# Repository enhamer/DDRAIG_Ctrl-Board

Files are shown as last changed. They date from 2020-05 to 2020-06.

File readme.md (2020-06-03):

<!---
#**============================================================================
#**
#**                    Ddraig Control Board
#**                  THIS REPOSITORY IS PART OF THE ENHAMER
#**
#** TITLE:           Ddraig Ctrl PCB (Circuit, Hardware)
#**
#** AUTHOR:          Marcin J. Kraśny
#**
#**					 Advanced Biological Imaging Laboratory
#**                  School of Physics
#**                  College of Science and Engineering
#**                  National University of Ireland, Galway
#**
#** SOURCE URL       https://github.com/enhamer/enhamer
#** COPYRIGHT        © 2015-2020 M.J.Kraśny
#** LICENSE          CERN-OHL-P v2
#** CREDITS          NEMESIS - Novel Energy Materials, Engineering Science 
#**                  and Integrated Systems
#**                  Department of Mechanical Engineering
#**					 University of Bath, UK
#**
#**============================================================================
#**============================================================================
-->
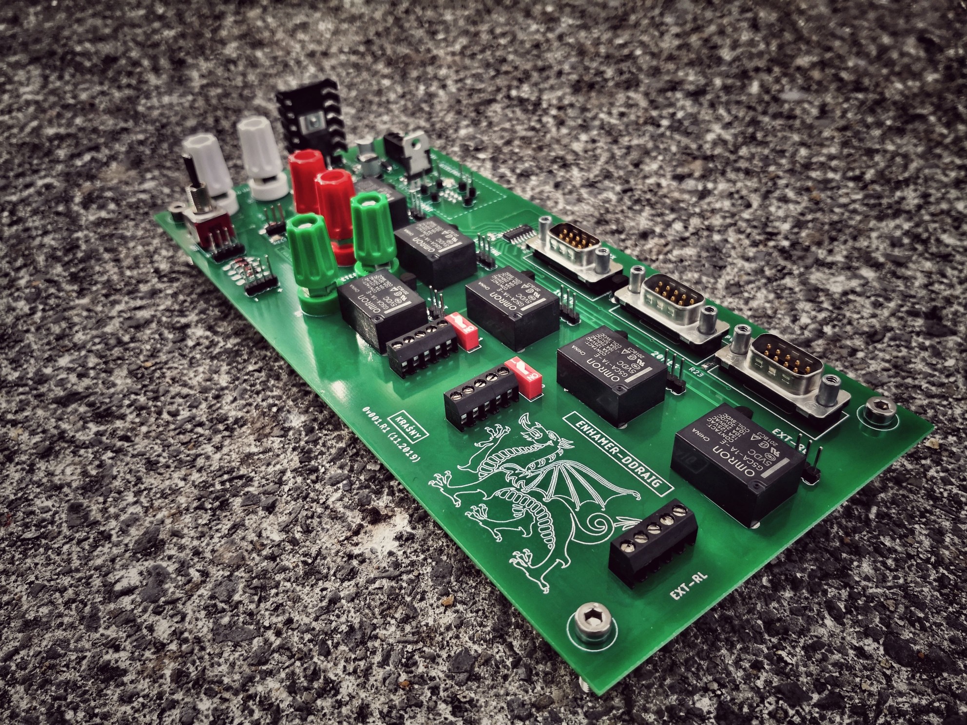
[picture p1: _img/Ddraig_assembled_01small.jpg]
Ddraig Board assembled


# DDRAIG - Control - Board
Part of:
**Energy Harvesting Measurement Rig (ENHAMER)**

*A System for Characterisation of Piezoelectric Materials and Associated Electronics for Vibration Powered Energy Harvesting Devices*

>For detailed **Information, Manuals and Description** please go to [**ENHAMER**](https://github.com/enhamer/enhamer/).

# Design software used
[EAGLE CAD](https://www.autodesk.com/products/eagle/overview)

## Ddraig Board Layout Top Side View
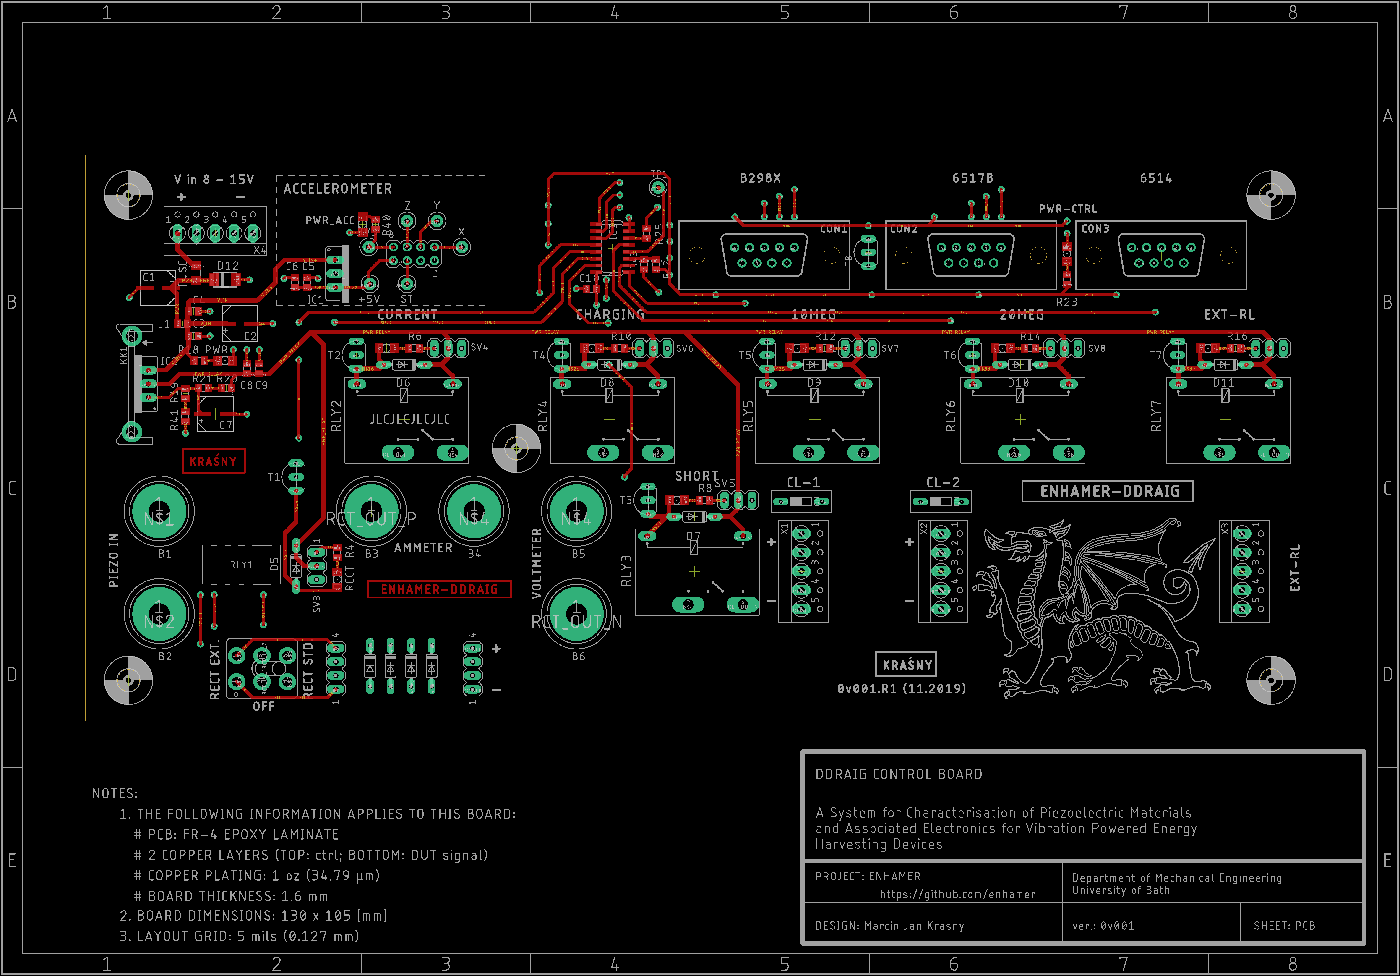
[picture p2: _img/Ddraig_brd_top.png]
Ddraig Board top


## Ddraig Board PCB
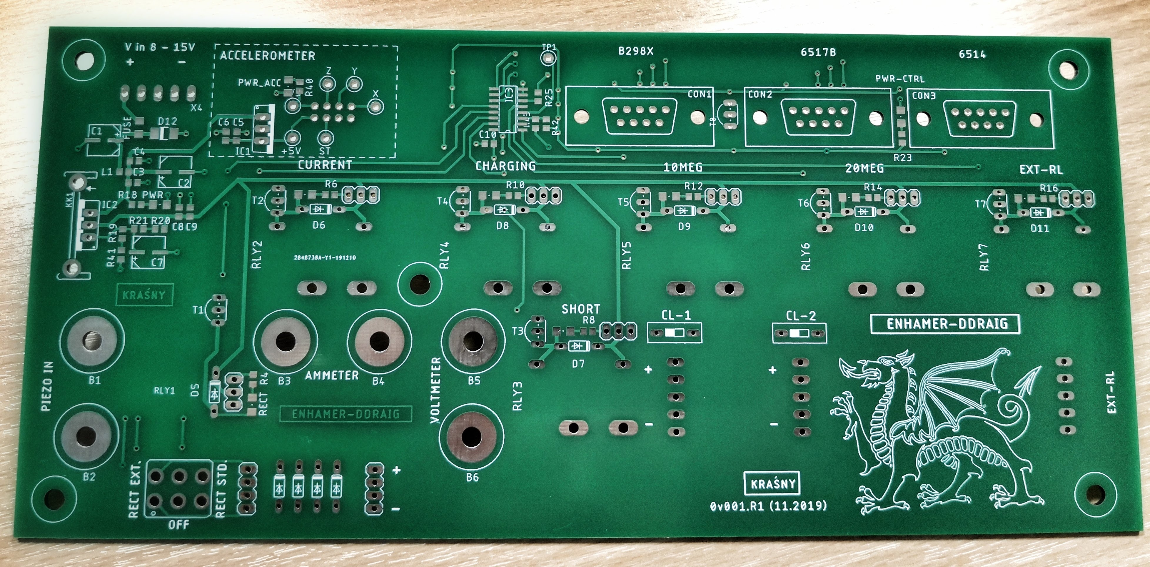
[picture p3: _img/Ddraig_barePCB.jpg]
Ddraig Board top


## Ddraig Board Assembled
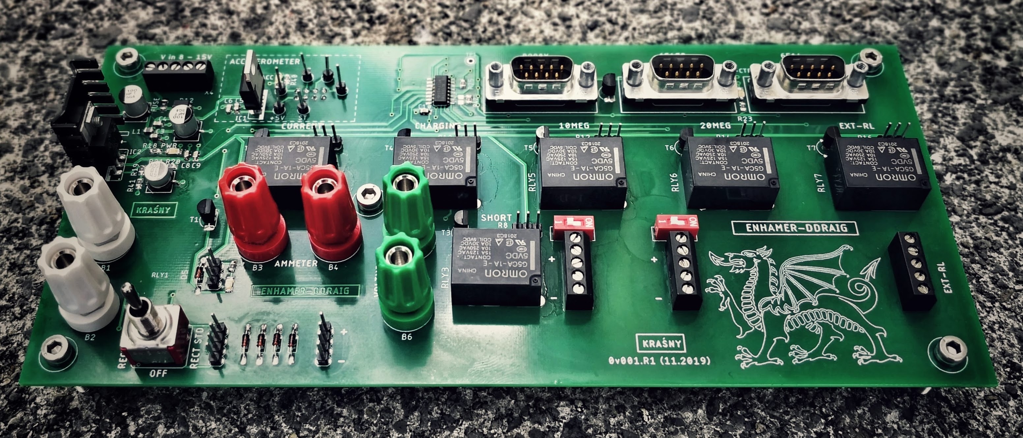
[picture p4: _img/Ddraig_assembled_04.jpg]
Ddraig Board assembled


# License
Copyright © 2015-2020 Marcin J. Kraśny

This work is licensed under the [CERN-OHL-P v2](LICENSE/cern_ohl_p_v2.txt); 
[CERN Open Hardware Licence version 2](https://cern.ch/cern-ohl).

You may redistribute and modify this documentation and make products
using it under the terms of the CERN-OHL-P v2 (<https:/cern.ch/cern-ohl>).
This documentation is distributed WITHOUT ANY EXPRESS OR IMPLIED WARRANTY INCLUDING OF MERCHANTABILITY, SATISFACTORY QUALITY AND FITNESS FOR A PARTICULAR PURPOSE. 
Please see the CERN-OHL-P v2 for applicable conditions.

# SOURCE
[https://github.com/enhamer](https://github.com/enhamer/enhamer/)

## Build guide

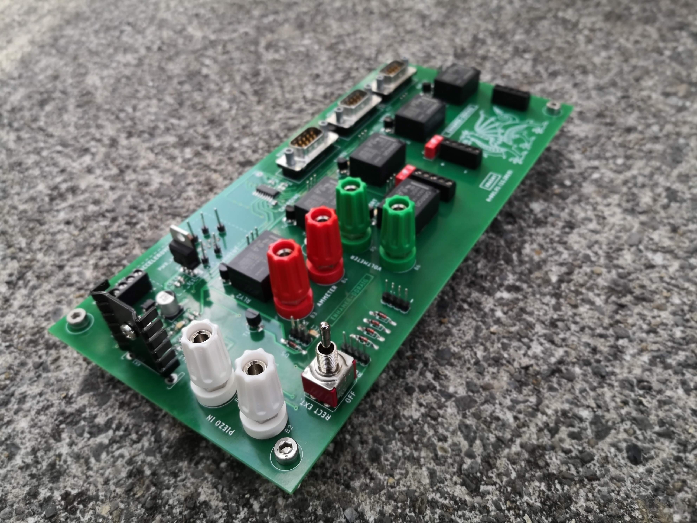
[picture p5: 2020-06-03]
_img/Ddraig_assembled_02.jpg

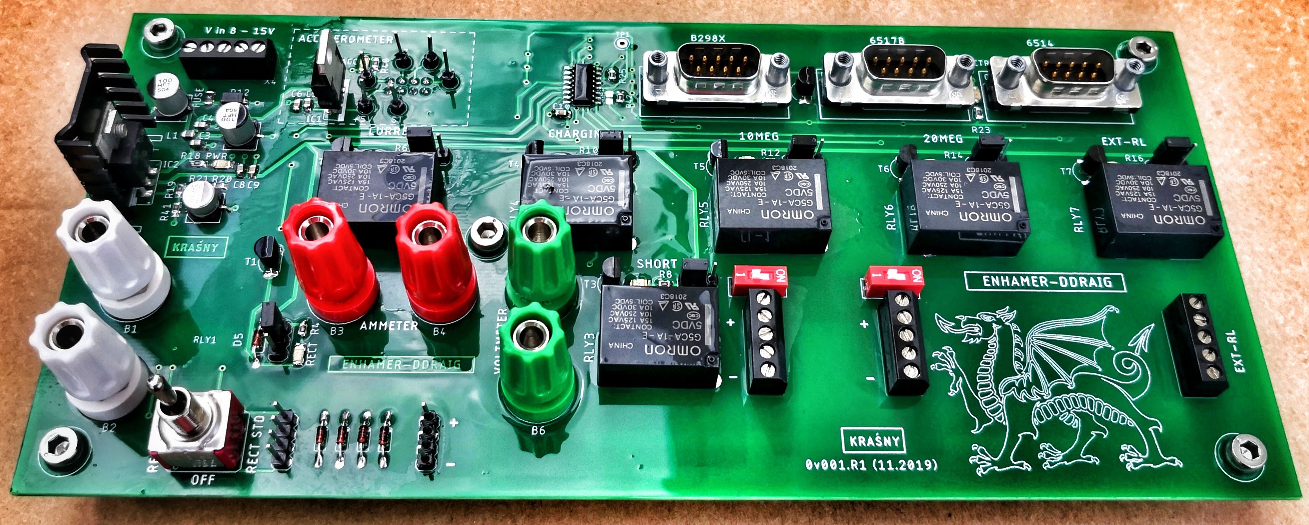
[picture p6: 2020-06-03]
_img/Ddraig_assembled_03.jpg

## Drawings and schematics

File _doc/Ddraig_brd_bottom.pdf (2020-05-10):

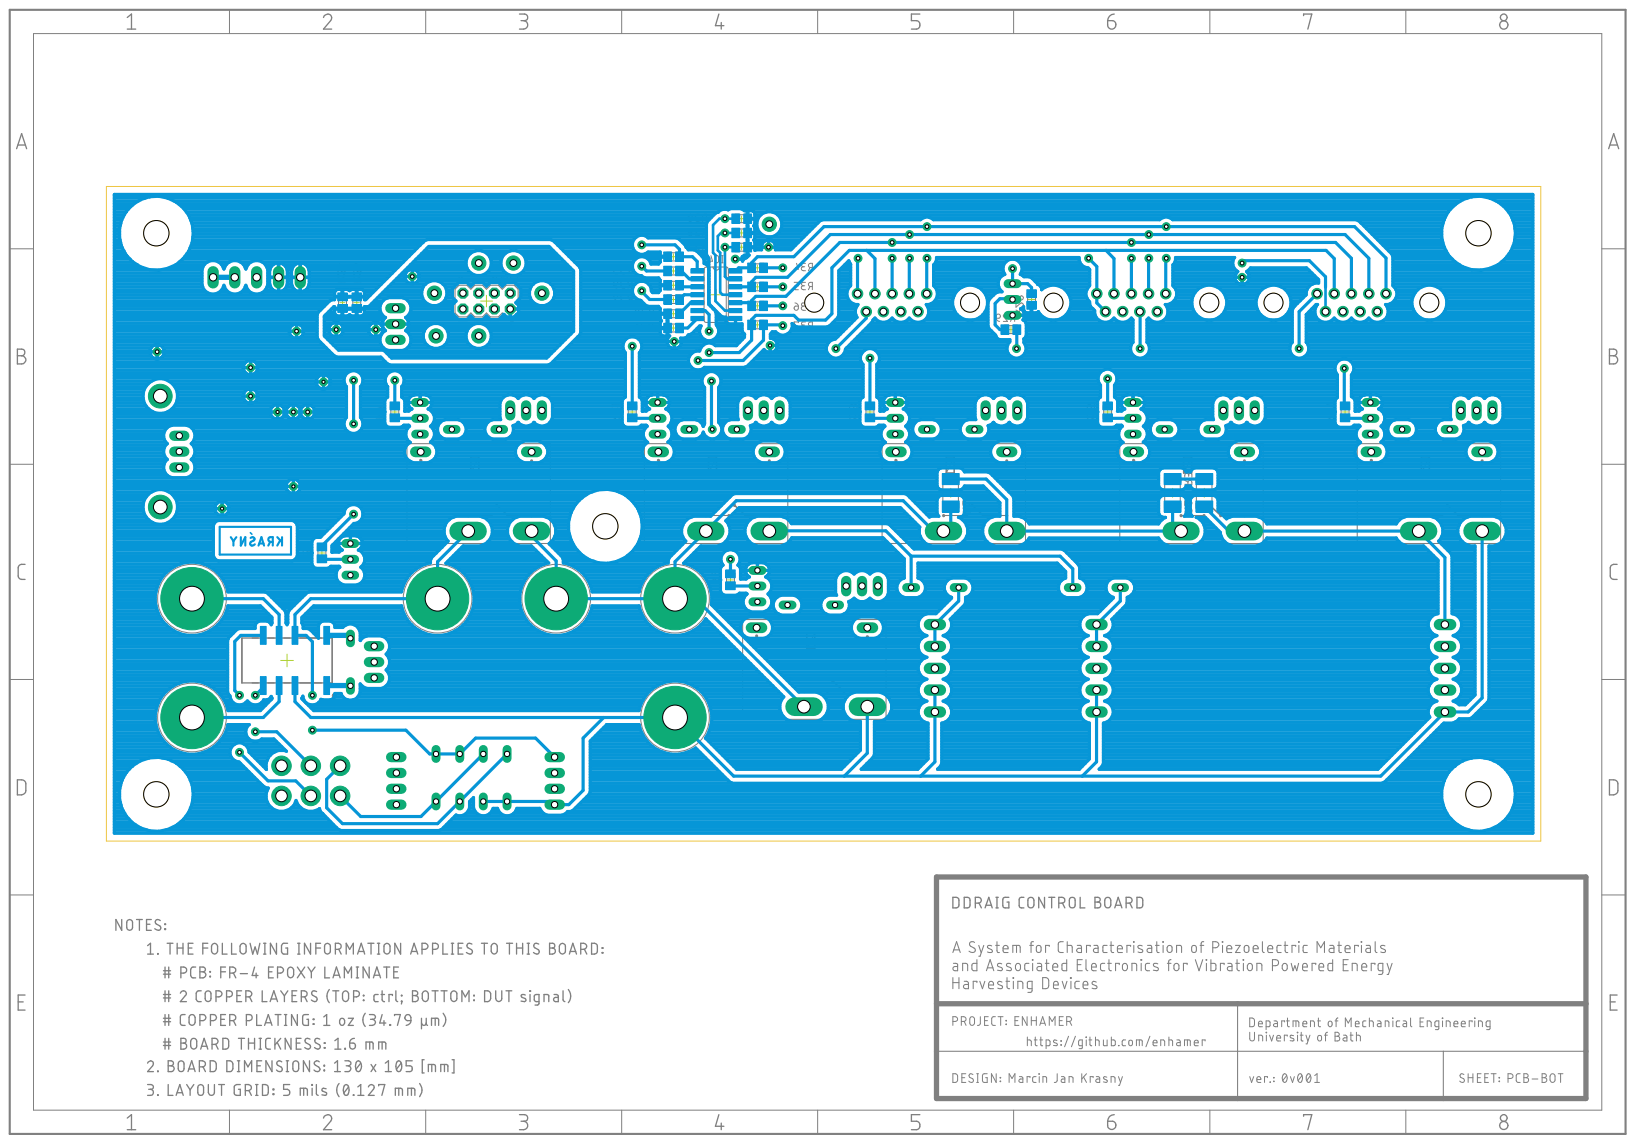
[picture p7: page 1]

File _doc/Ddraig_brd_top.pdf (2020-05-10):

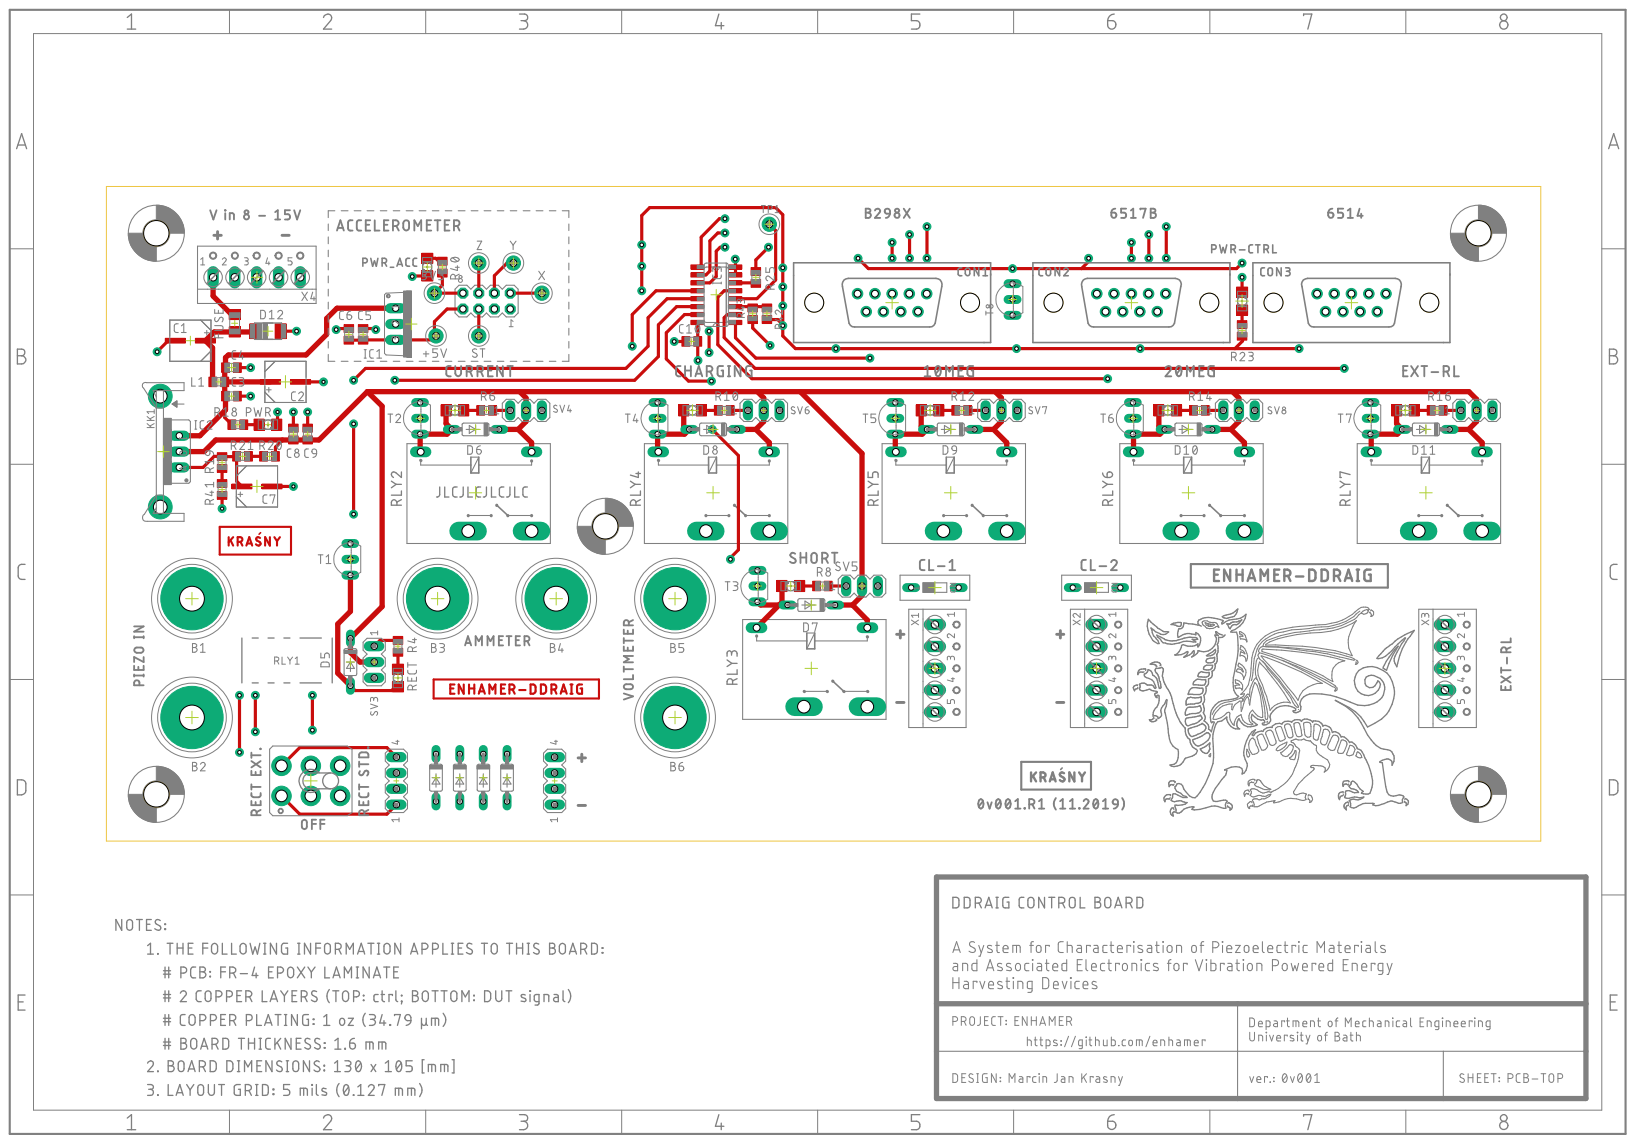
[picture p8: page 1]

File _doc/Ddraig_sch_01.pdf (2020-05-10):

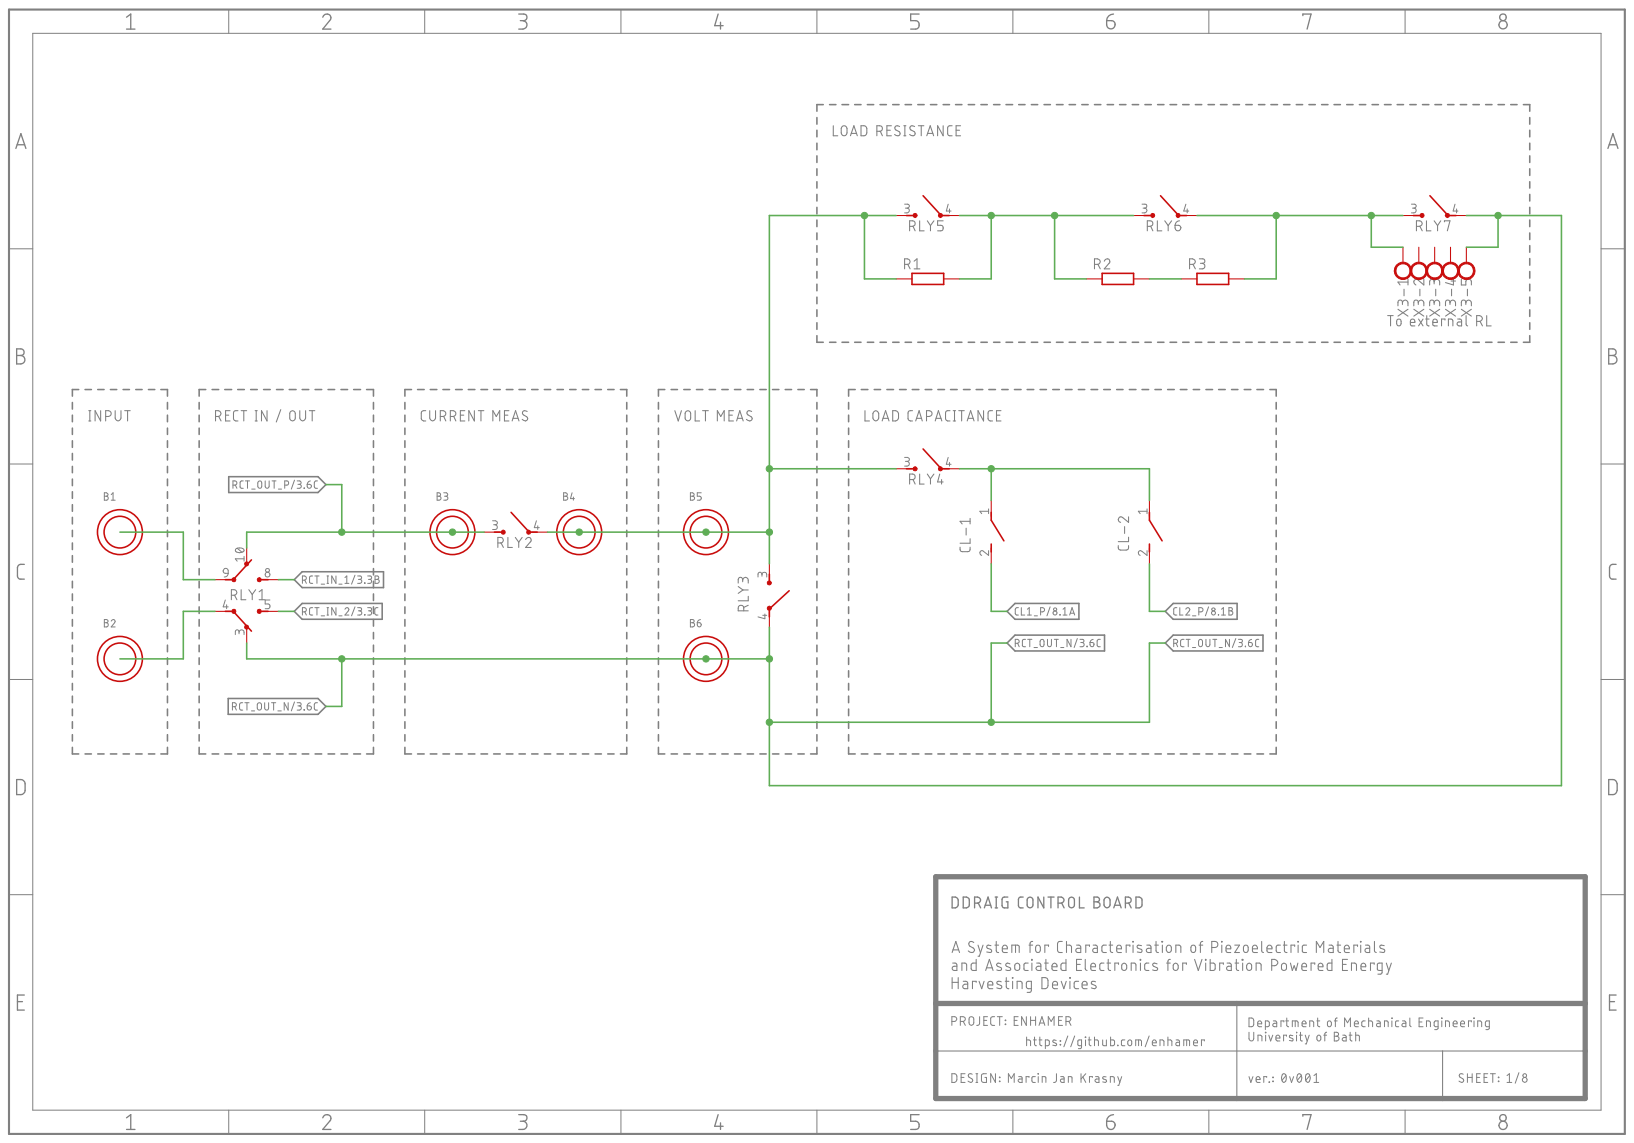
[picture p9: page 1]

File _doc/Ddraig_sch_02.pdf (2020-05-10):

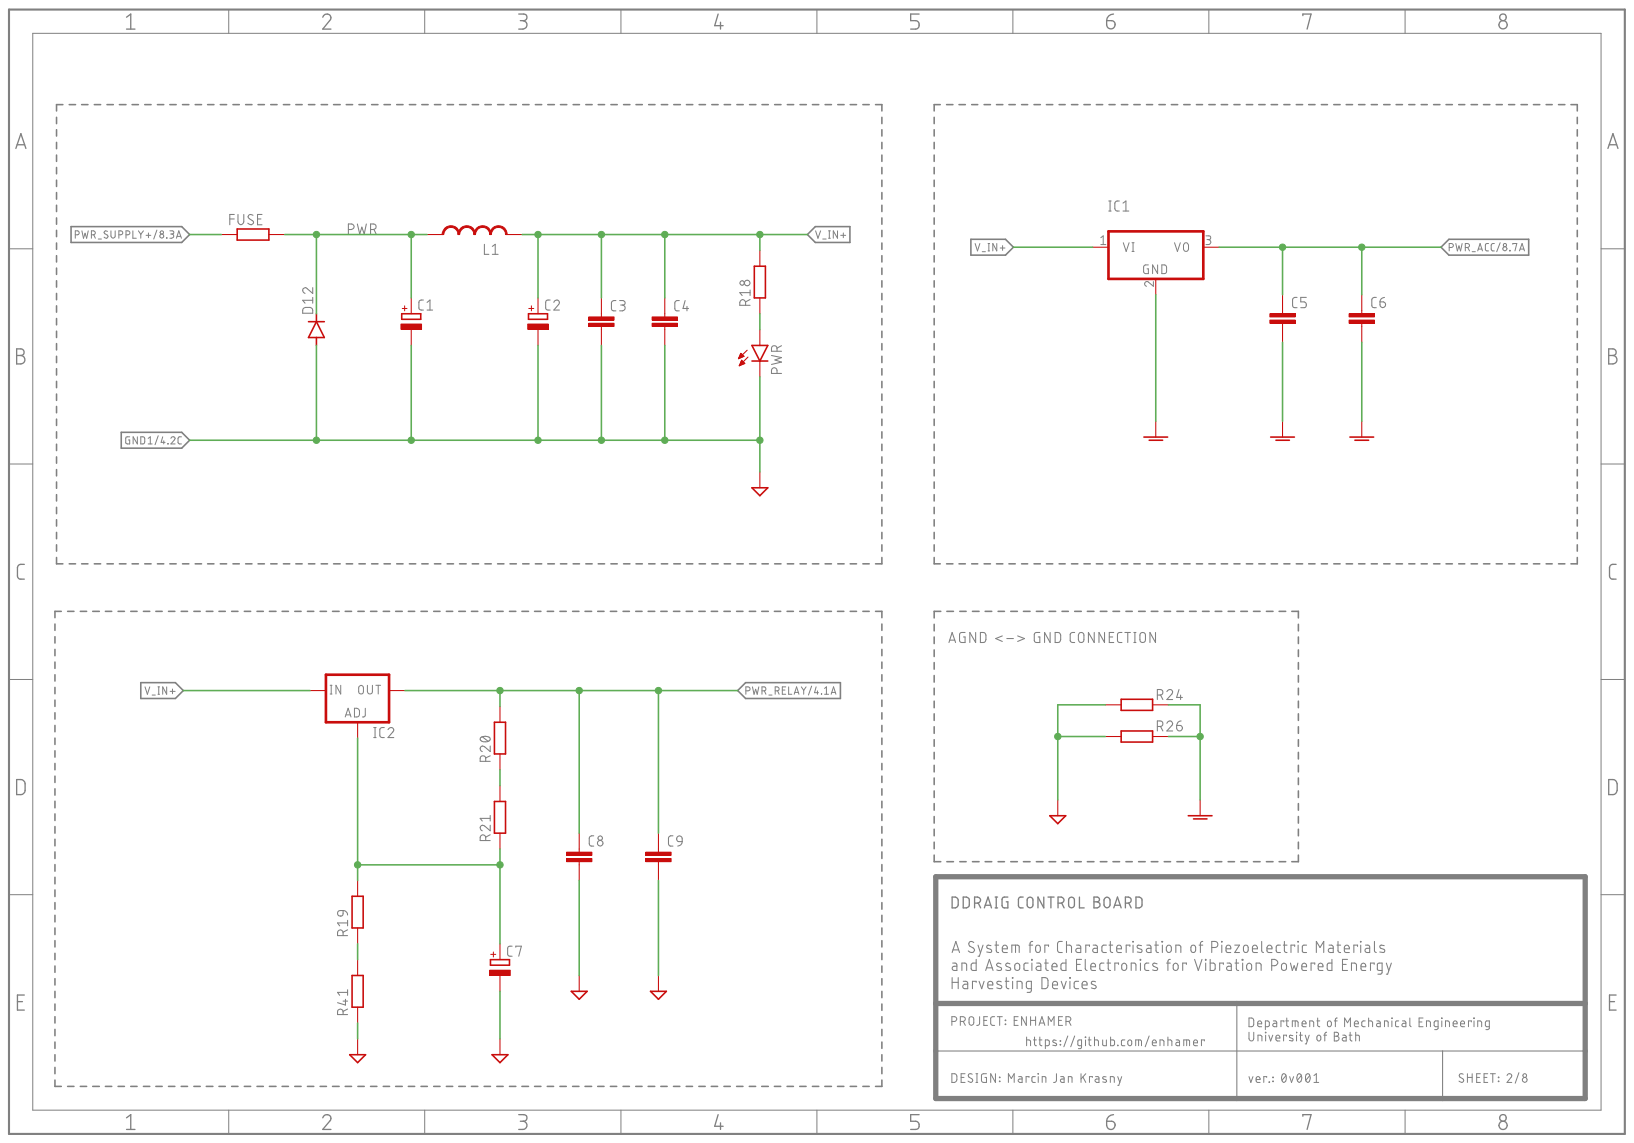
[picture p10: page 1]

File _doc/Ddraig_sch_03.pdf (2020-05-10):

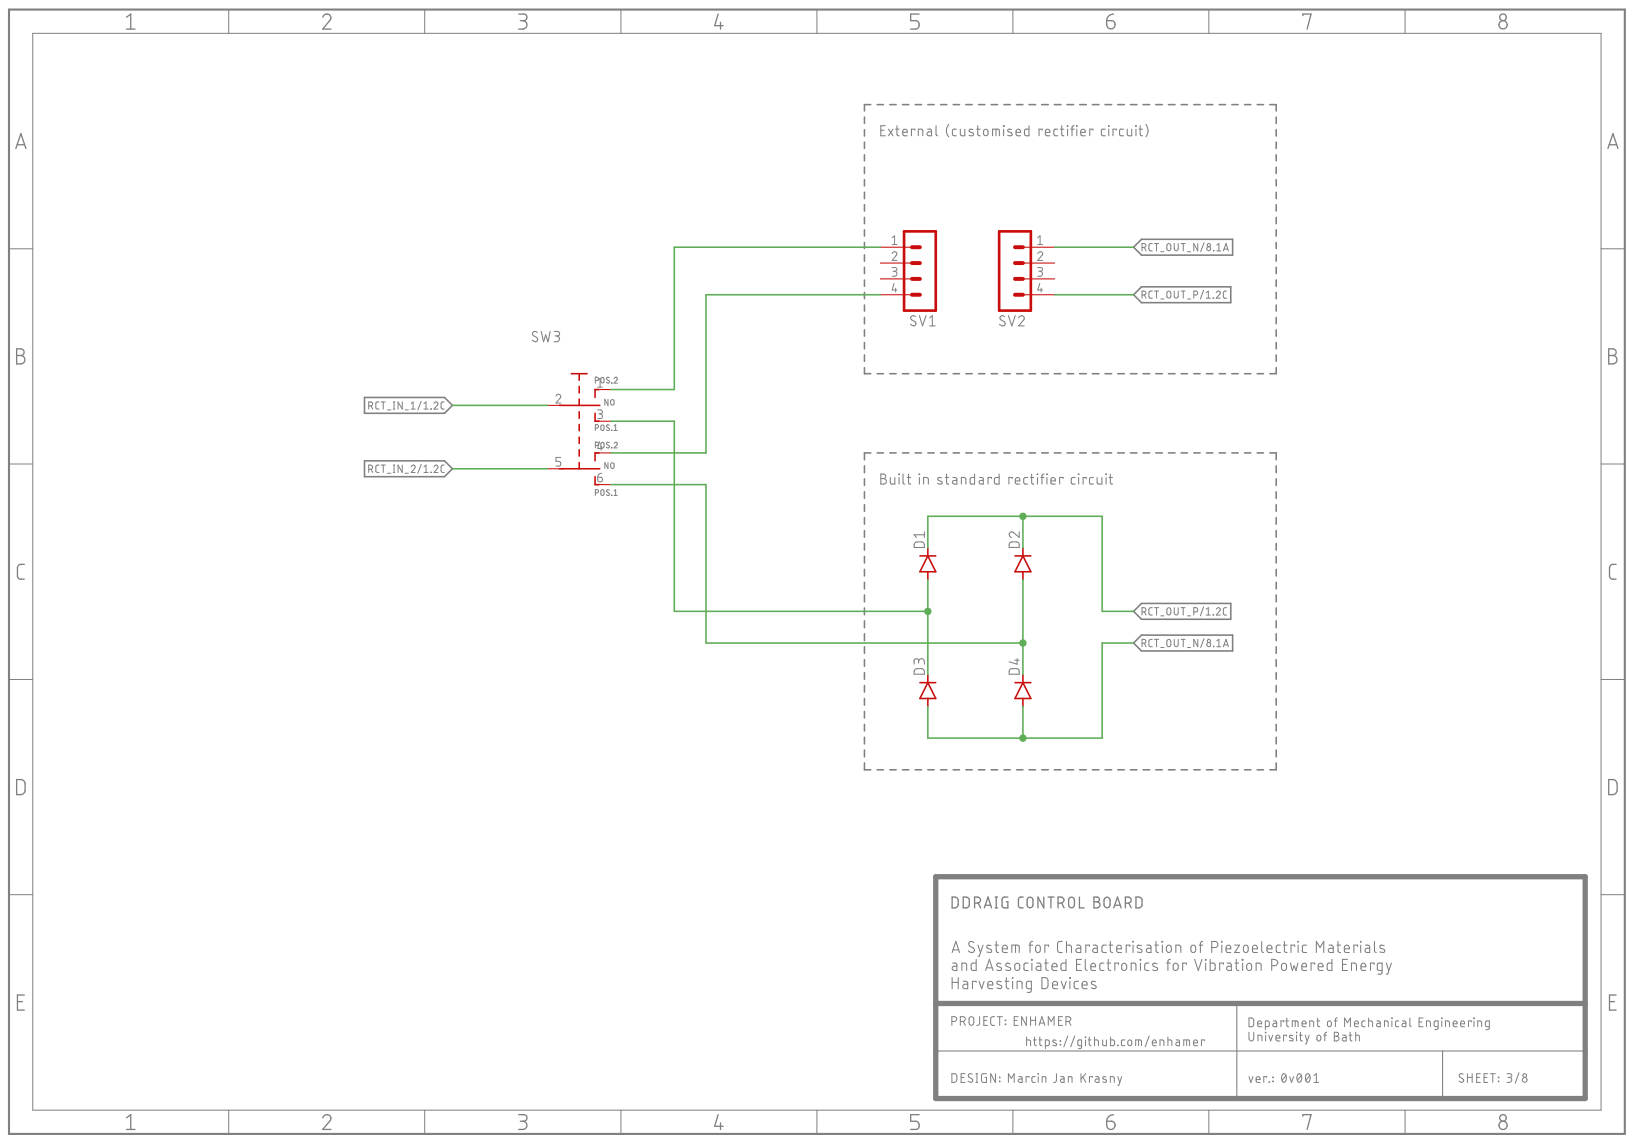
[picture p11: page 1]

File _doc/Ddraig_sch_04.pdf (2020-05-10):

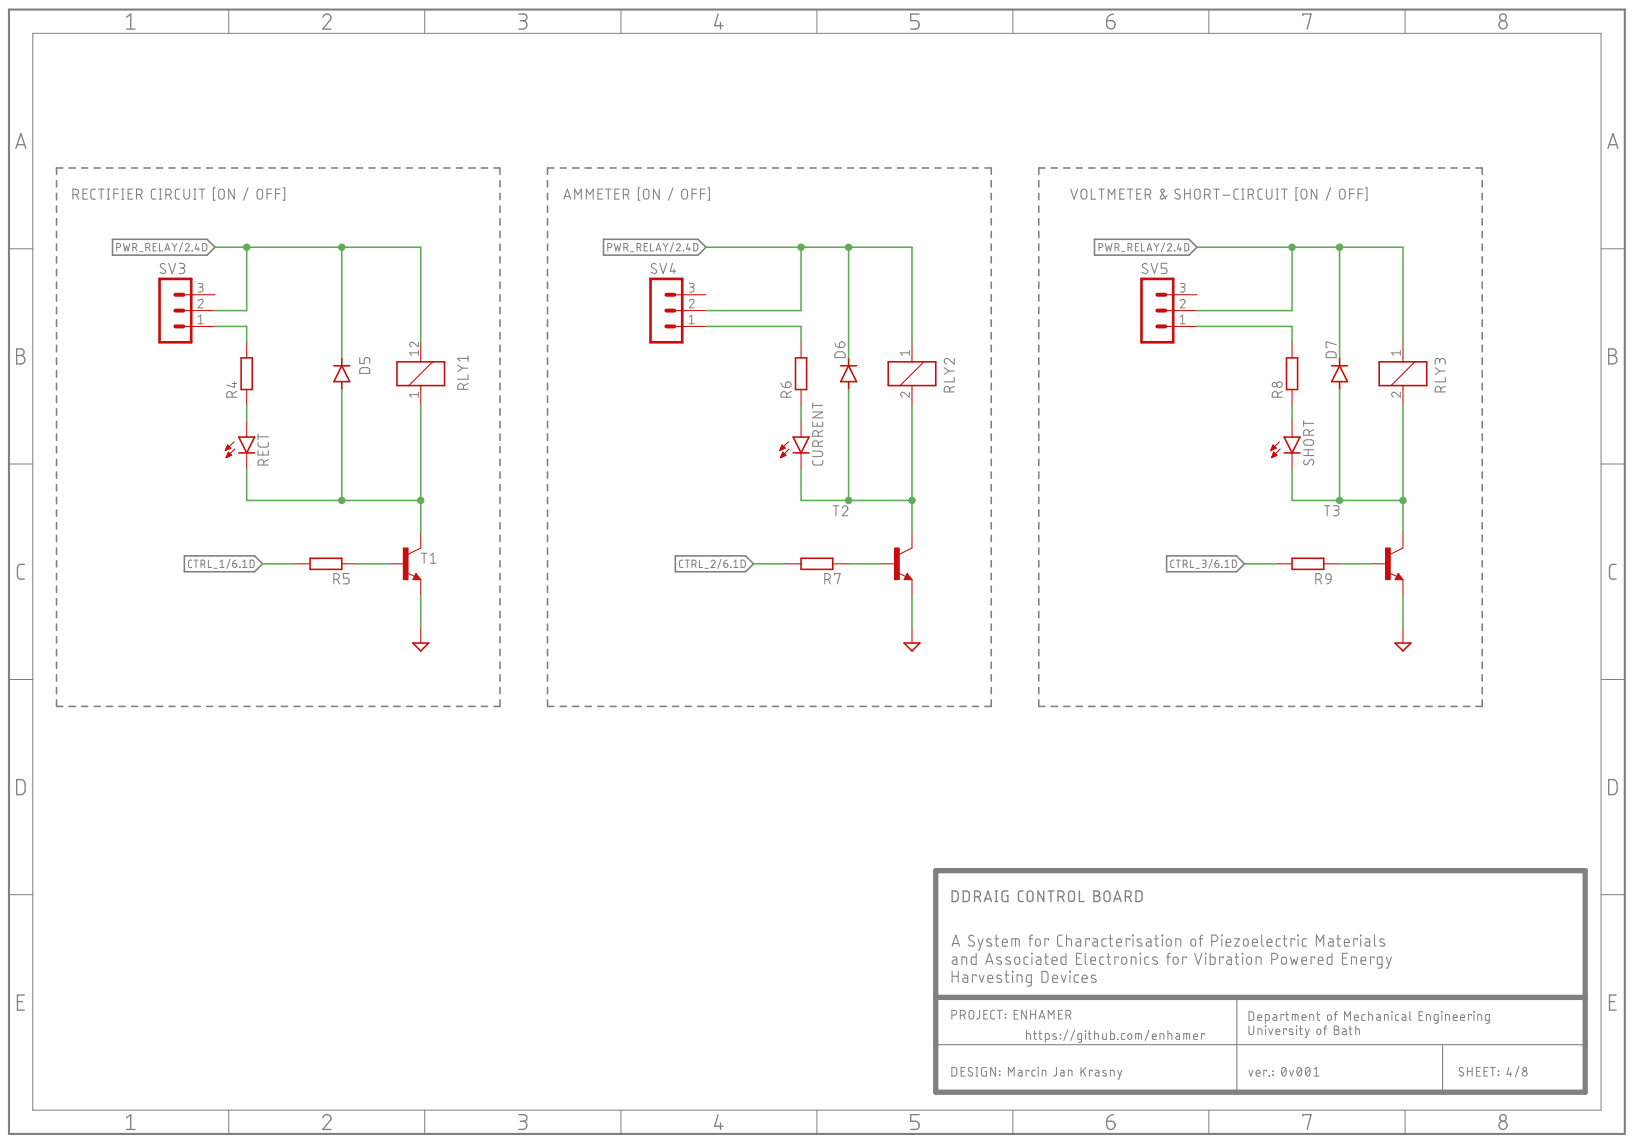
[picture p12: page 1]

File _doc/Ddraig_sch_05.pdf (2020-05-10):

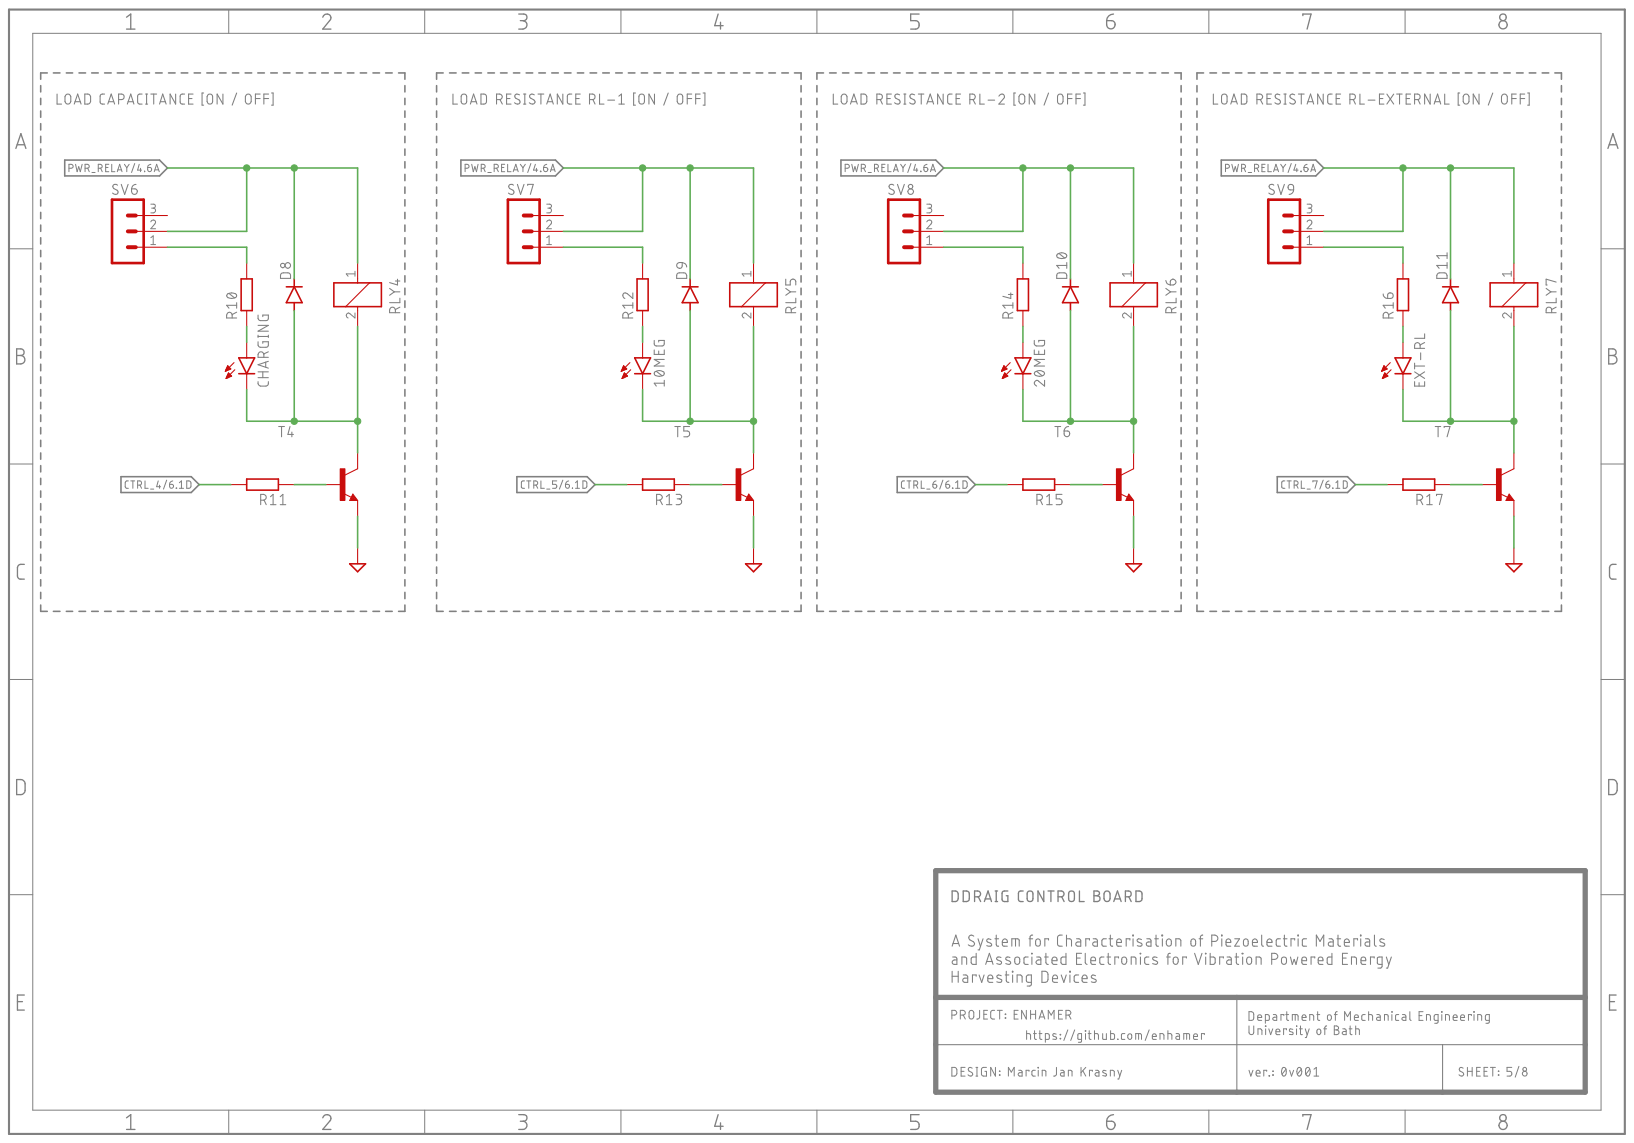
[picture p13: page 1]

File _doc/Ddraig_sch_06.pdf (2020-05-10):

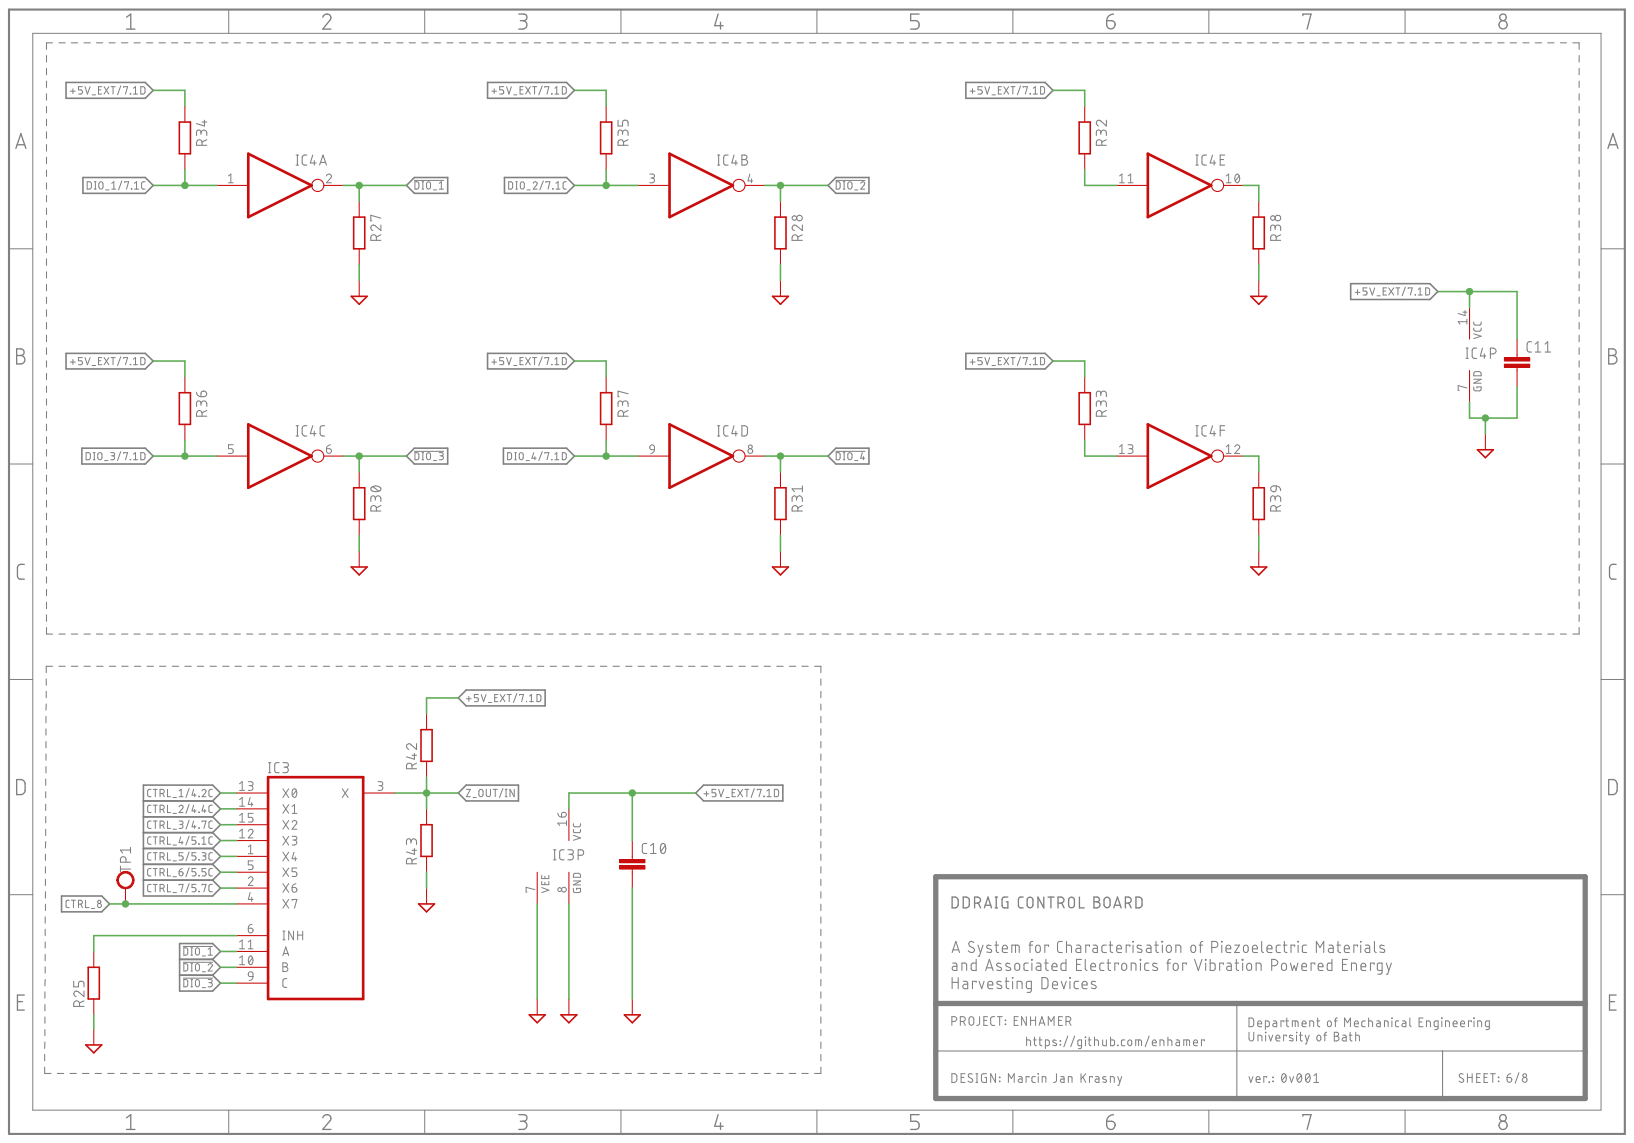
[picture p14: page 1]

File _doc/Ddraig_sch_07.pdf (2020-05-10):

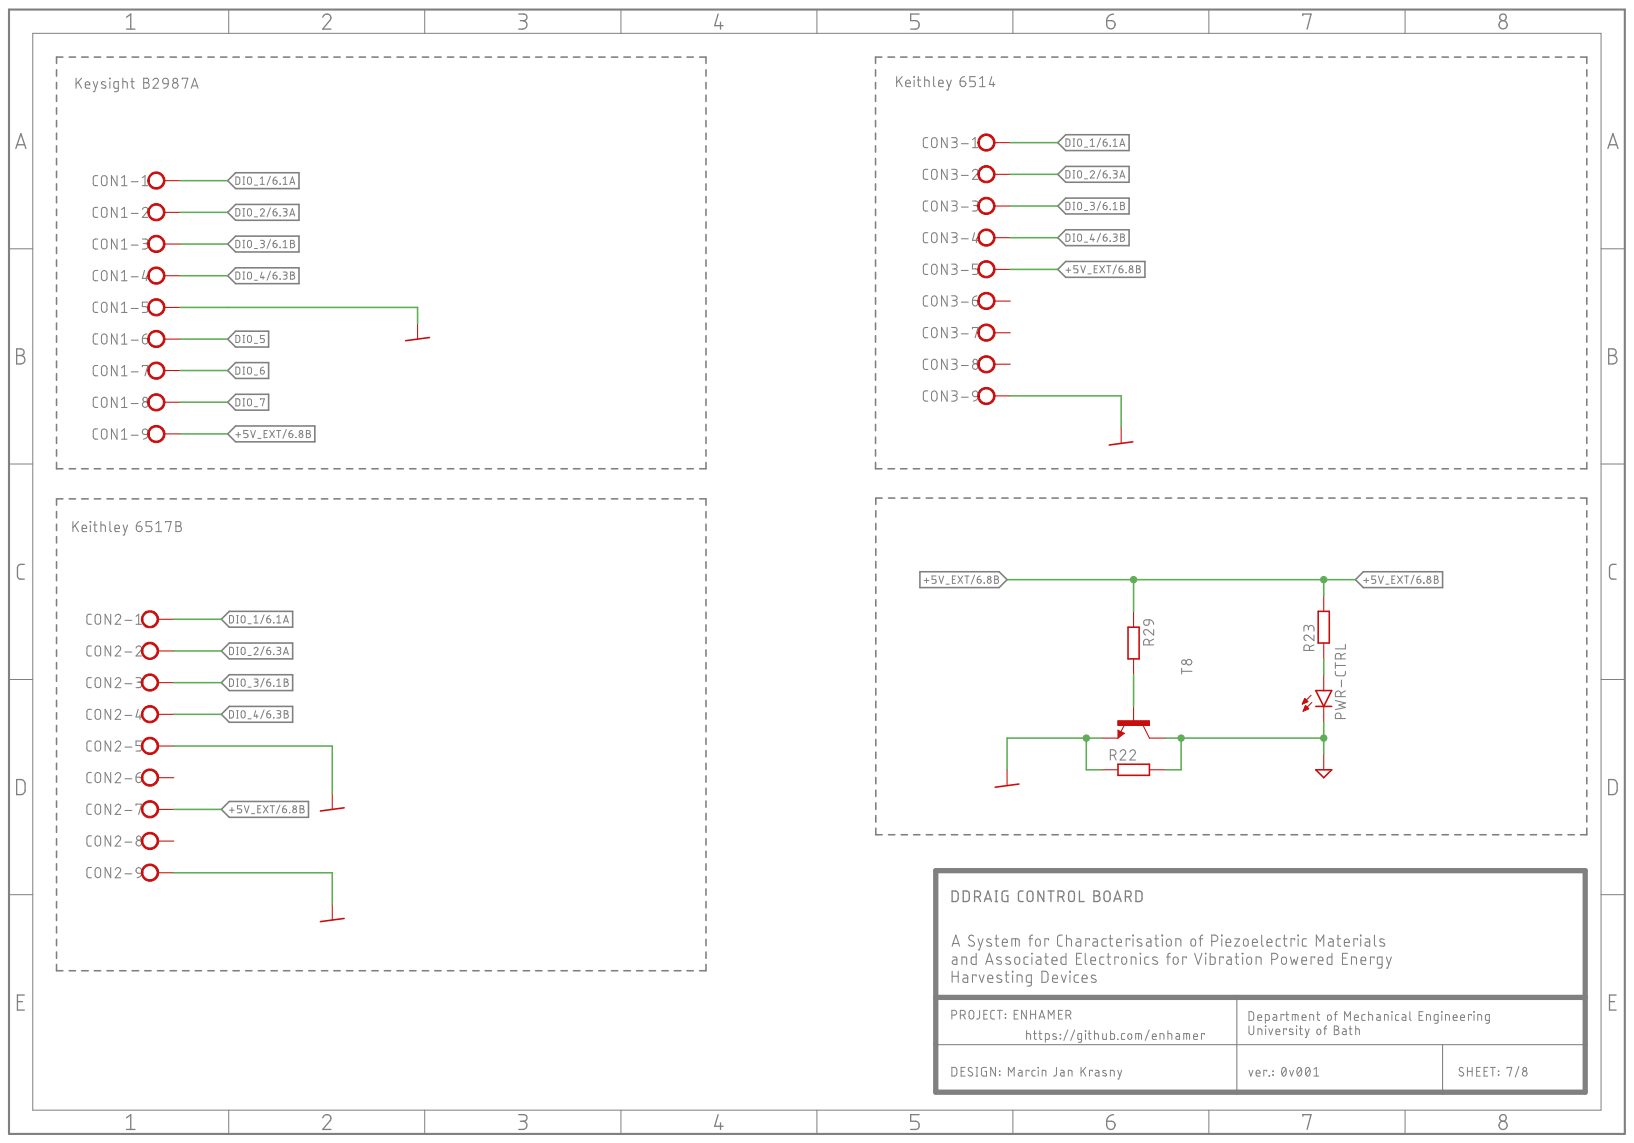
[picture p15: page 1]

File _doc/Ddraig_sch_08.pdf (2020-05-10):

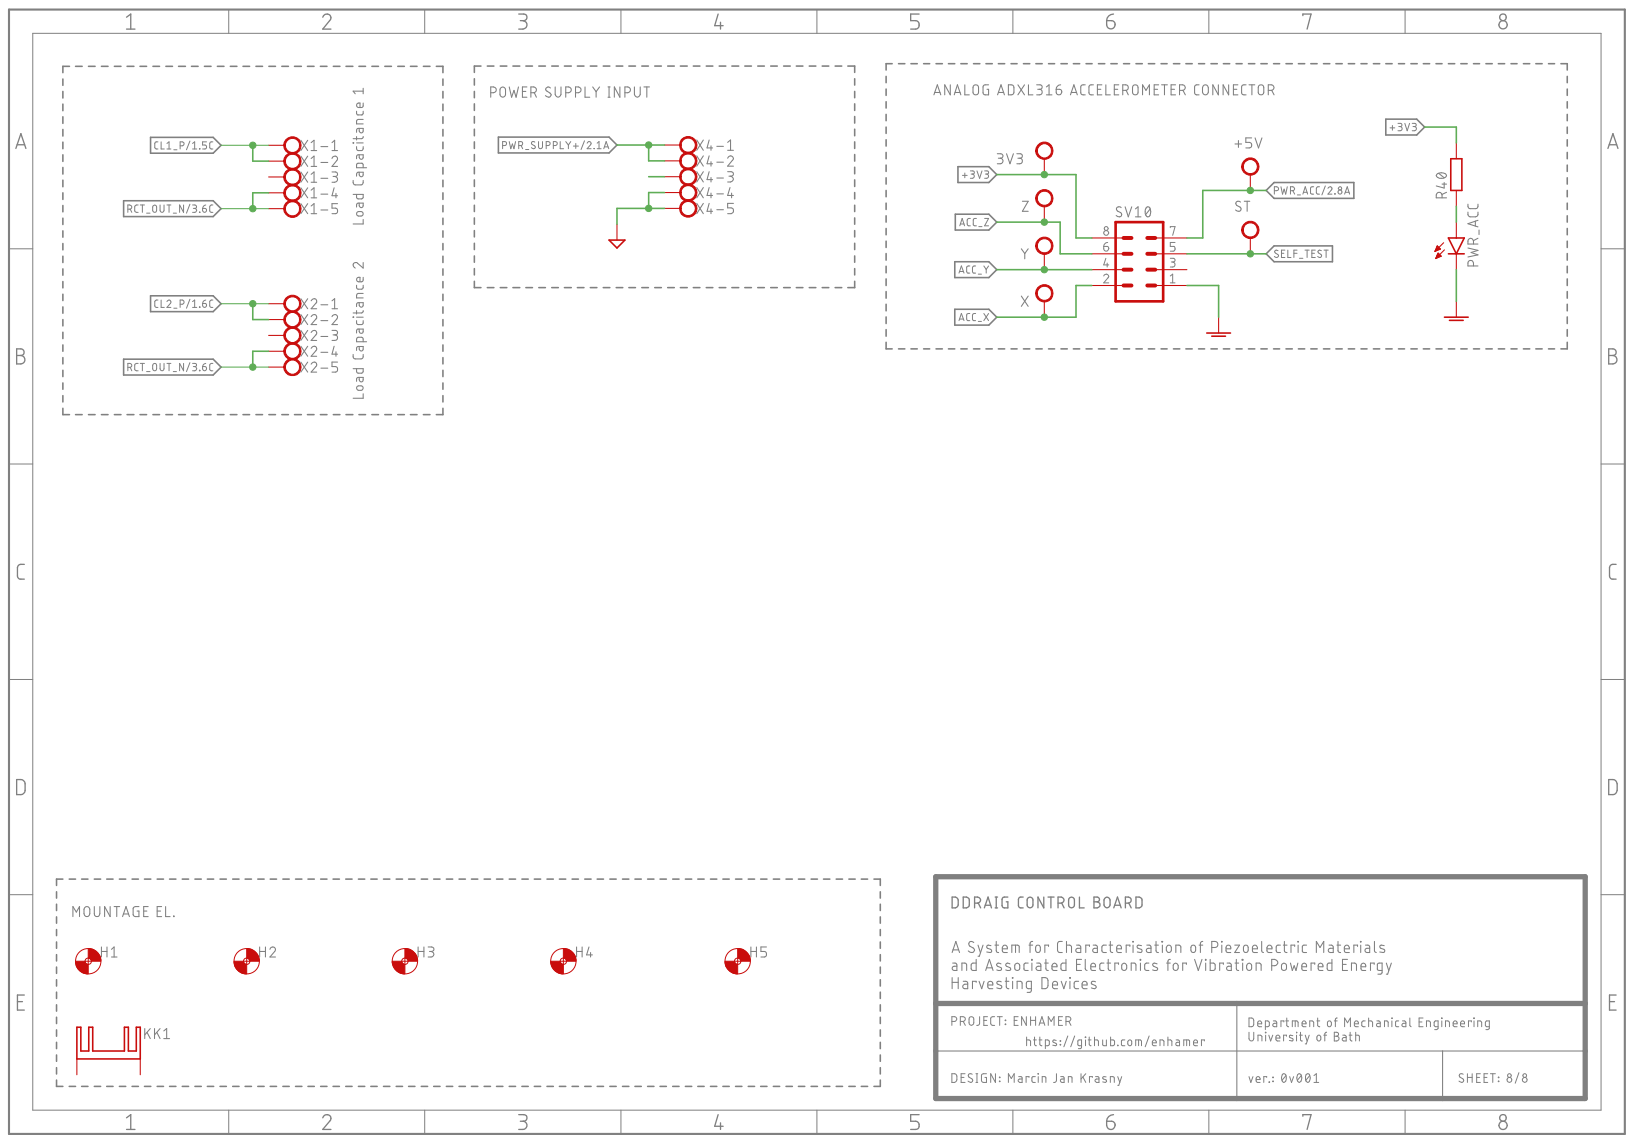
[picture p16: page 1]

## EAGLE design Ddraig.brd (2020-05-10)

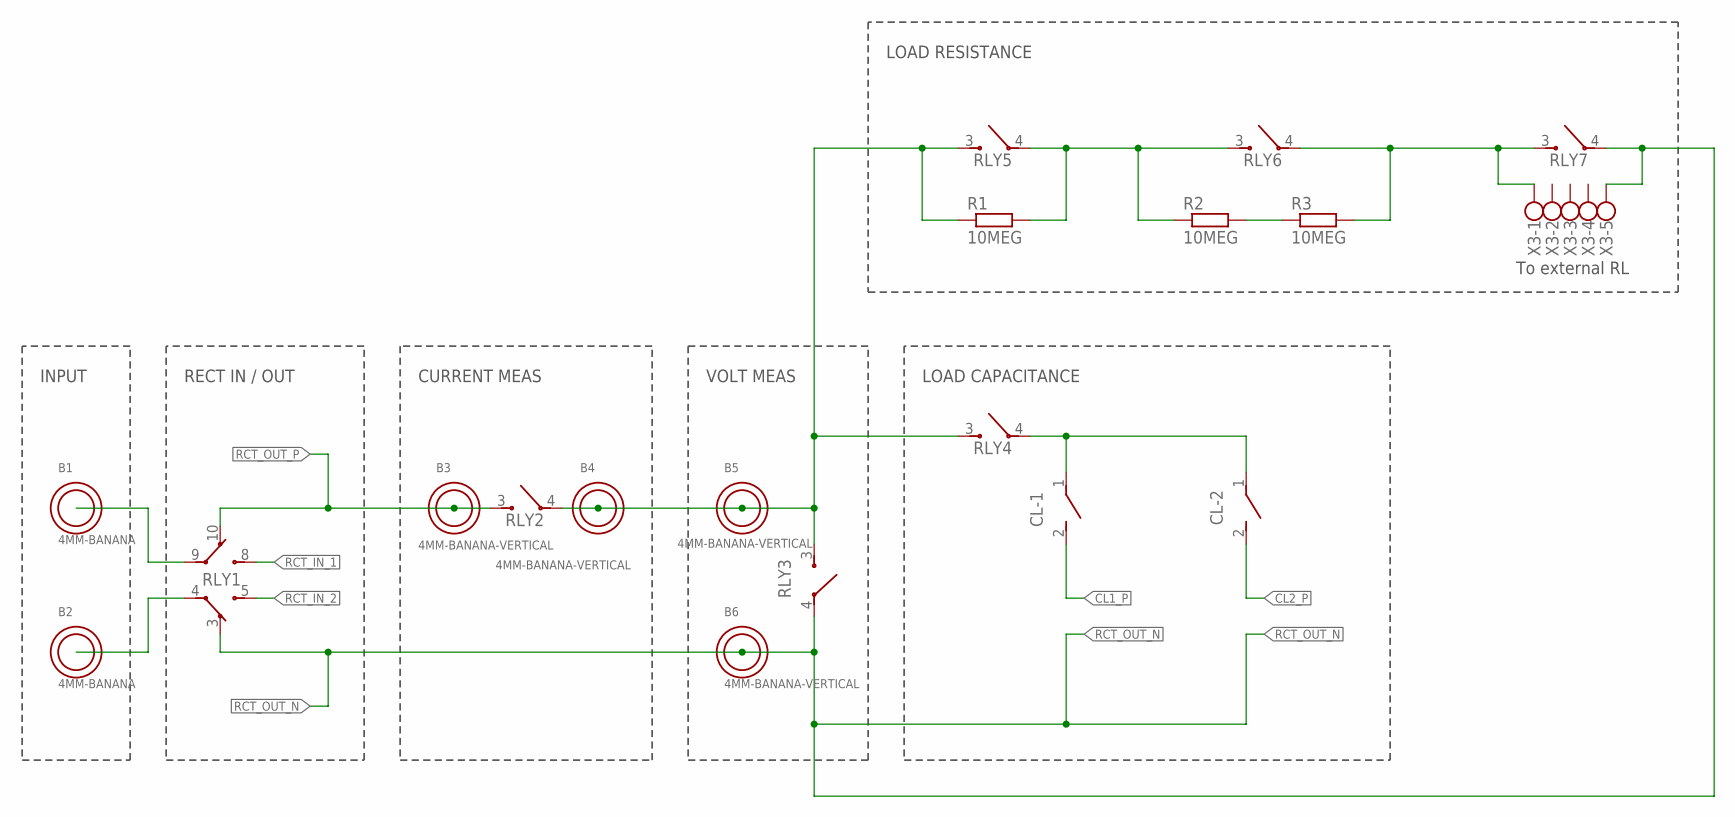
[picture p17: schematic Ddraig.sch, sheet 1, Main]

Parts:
B1, B2: 4MM-BANANA; 4MM-BANANA-VERTICAL
B3, B4, B5, B6: 4MM-BANANA-VERTICAL
CL-1, CL-2: DIP_SWITCH_01
R1, R2, R3: 10MEG; R2010
RLY1: AXICOM-V23079-D; AXICOM-V23079-SMT_MONO
RLY2, RLY3, RLY4, RLY5, RLY6, RLY7: OMRON-G5CA-1A-E; G5CA_MJK
X3: 5PIN_CONN_RAST3.5MM

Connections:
CL1_P: CL-1.2; also elsewhere on the board
CL2_P: CL-2.2; also elsewhere on the board
unnamed: B1.1, RLY1.9 (1)
unnamed: B2.1, RLY1.4
unnamed: B4.1, B5.1, R1.1, RLY2.4 (1), RLY3.3, RLY4.3, RLY5.3
unnamed: R3.2, RLY6.4 (1), RLY7.3, X3.1
unnamed: CL-1.1, CL-2.1, RLY4.4 (1)
unnamed: R1.2, R2.1, RLY5.4 (1), RLY6.3
unnamed: R2.2, R3.1
RCT_IN_1: RLY1.8 (3); also elsewhere on the board
RCT_IN_2: RLY1.5 (6); also elsewhere on the board
RCT_OUT_N: B6.1, RLY1.3 (5), RLY3.4 (1), RLY7.4 (1), X3.5; also elsewhere on the board
RCT_OUT_P: B3.1, RLY1.10 (2), RLY2.3; also elsewhere on the board

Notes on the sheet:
CURRENT MEAS
VOLT MEAS
LOAD CAPACITANCE
LOAD RESISTANCE
INPUT
RECT IN / OUT
To external RL

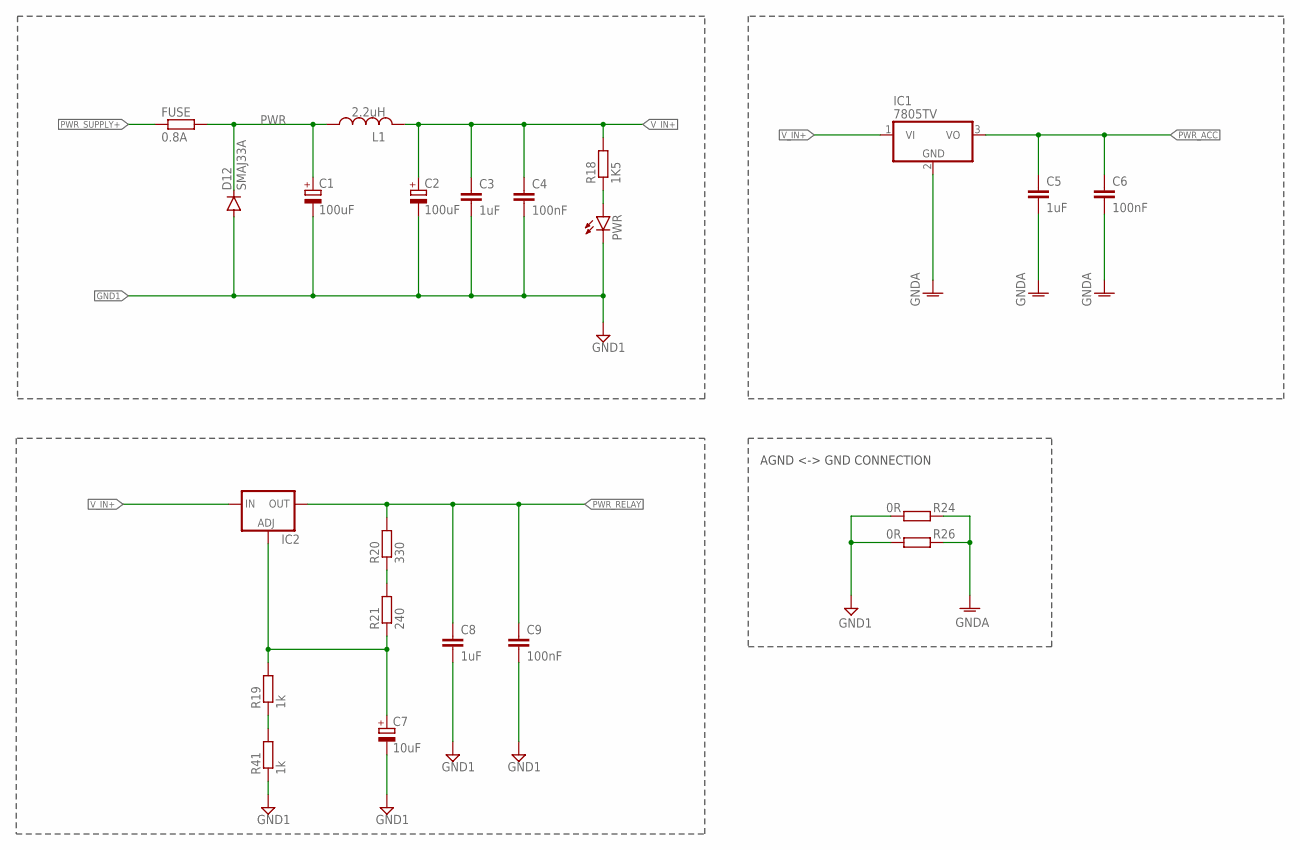
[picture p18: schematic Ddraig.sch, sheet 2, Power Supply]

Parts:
C1, C2: 100uF; PANASONIC-CAPAE660X800N
C3, C5, C8: 1uF; C0805
C4, C6, C9: 100nF; C0805
C7: 10uF; PANASONIC-CAPAE660X800N
D12: SMAJ33A; DO-214AC
FUSE: 0.8A; 1206
IC1: 7805TV; TO220V
IC2: LM317TS; 317TS
L1: 2.2uH; 0805
PWR: LEDSMT1206; 1206
R18: 1K5; R0805
R19, R41: 1k; R0805
R20: 330; R0805
R21: 240; R0805
R24, R26: 0R; R0805

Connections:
GND1: C1.2 (-), C2.2 (-), C3.2, C4.2, C7.2 (-), C8.2, C9.2, D12.A, PWR.C, R24.2, R26.2, R41.1; also elsewhere on the board
GNDA: C5.2, C6.2, IC1.2 (GND), R24.1, R26.1; also elsewhere on the board
unnamed: PWR.A, R18.1
unnamed: C7.1 (+), IC2.1 (ADJ), R19.2, R21.1
unnamed: R20.1, R21.2
unnamed: R19.1, R41.2
PWR: C1.1 (+), D12.C, FUSE.2, L1.1
PWR_ACC: C5.1, C6.1, IC1.3 (VO); also elsewhere on the board
PWR_RELAY: C8.1, C9.1, IC2.2 (OUT), R20.2; also elsewhere on the board
PWR_SUPPLY+: FUSE.1; also elsewhere on the board
V_IN+: C2.1 (+), C3.1, C4.1, IC1.1 (VI), IC2.3 (IN), L1.2, R18.2

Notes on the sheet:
AGND <-> GND CONNECTION

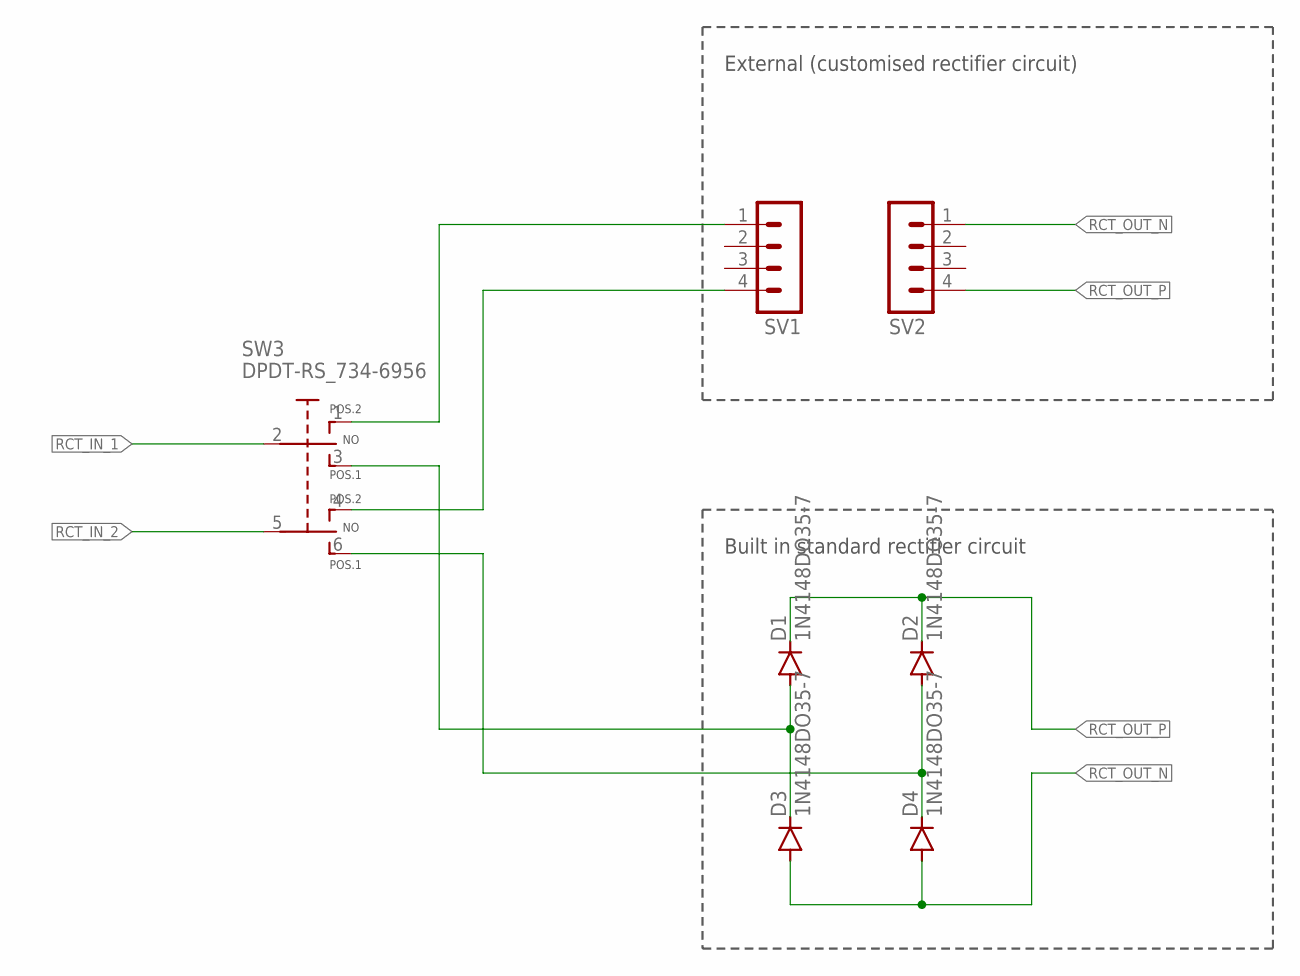
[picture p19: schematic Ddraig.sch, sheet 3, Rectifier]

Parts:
D1, D2, D3, D4: 1N4148DO35-7; DO35-7
SV1, SV2: MA04-1
SW3: DPDT-RS_734-6956

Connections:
unnamed: SV1.1, SW3.1
unnamed: SV1.4, SW3.4
unnamed: D1.A, D3.C, SW3.3
unnamed: D2.A, D4.C, SW3.6
RCT_IN_1: SW3.2; also elsewhere on the board
RCT_IN_2: SW3.5; also elsewhere on the board
RCT_OUT_N: D3.A, D4.A, SV2.1; also elsewhere on the board
RCT_OUT_P: D1.C, D2.C, SV2.4; also elsewhere on the board

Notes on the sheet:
External (customised rectifier circuit)
Built in standard rectifier circuit

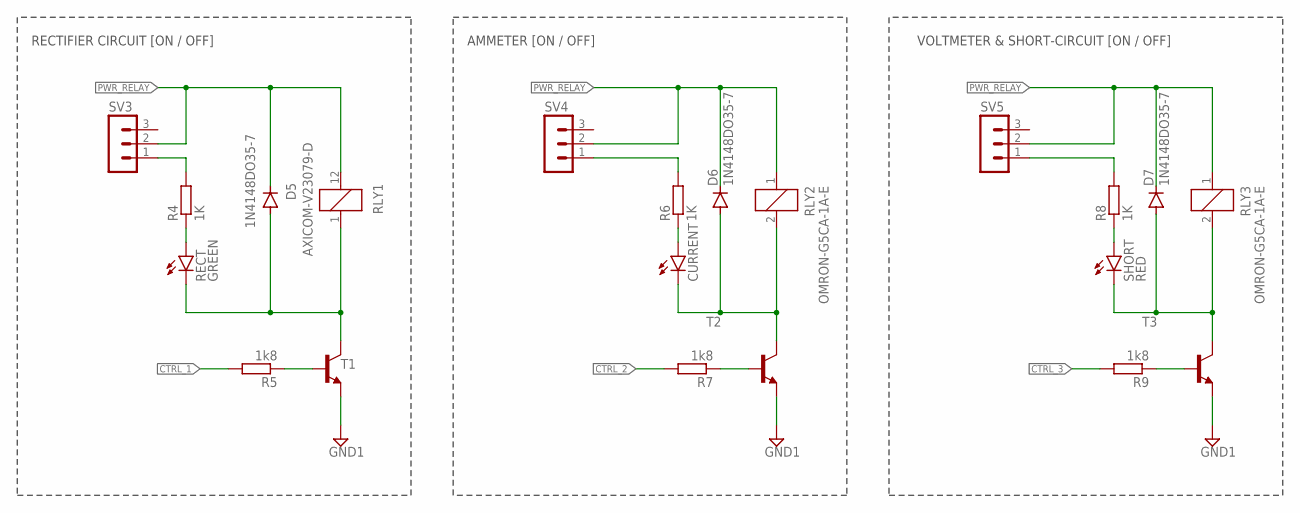
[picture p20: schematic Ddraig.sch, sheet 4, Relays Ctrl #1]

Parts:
CURRENT: LEDSMT1206; 1206
D5, D6, D7: 1N4148DO35-7; DO35-7
R4, R6, R8: 1K; R0805
R5, R7, R9: 1k8; R0805
RECT: GREEN; 1206
RLY1: AXICOM-V23079-D; AXICOM-V23079-SMT_MONO
RLY2, RLY3: OMRON-G5CA-1A-E; G5CA_MJK
SHORT: RED; 1206
SV3, SV4, SV5: MA03-1
T1, T2, T3: BC337-25-NPN-TO92-CBE; TO92-CBE

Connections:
CTRL_1: R5.2; also elsewhere on the board
CTRL_2: R7.2; also elsewhere on the board
CTRL_3: R9.2; also elsewhere on the board
GND1: T1.E, T2.E, T3.E; also elsewhere on the board
unnamed: R4.2, SV3.1
unnamed: R4.1, RECT.A
unnamed: D5.A, RECT.C, RLY1.1, T1.C
unnamed: CURRENT.A, R6.1
unnamed: CURRENT.C, D6.A, RLY2.2, T2.C
unnamed: R5.1, T1.B
unnamed: R6.2, SV4.1
unnamed: R7.1, T2.B
unnamed: R8.1, SHORT.A
unnamed: D7.A, RLY3.2, SHORT.C, T3.C
unnamed: R8.2, SV5.1
unnamed: R9.1, T3.B
PWR_RELAY: D5.C, D6.C, D7.C, RLY1.12 (2), RLY2.1, RLY3.1, SV3.2, SV4.2, SV5.2; also elsewhere on the board

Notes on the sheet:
RECTIFIER CIRCUIT [ON / OFF]
AMMETER [ON / OFF]
VOLTMETER & SHORT-CIRCUIT [ON / OFF]

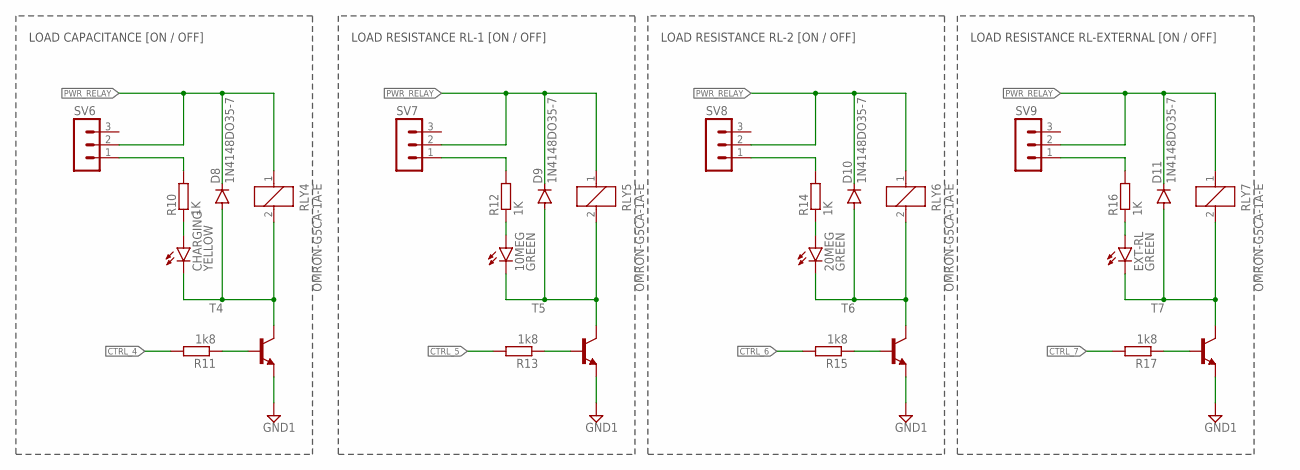
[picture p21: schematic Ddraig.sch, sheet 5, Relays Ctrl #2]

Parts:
10MEG, 20MEG: GREEN; 1206
CHARGING: YELLOW; 1206
D8, D9, D10, D11: 1N4148DO35-7; DO35-7
EXT-RL: GREEN; 1206
R10, R12, R14, R16: 1K; R0805
R11, R13, R15, R17: 1k8; R0805
RLY4, RLY5, RLY6, RLY7: OMRON-G5CA-1A-E; G5CA_MJK
SV6, SV7, SV8, SV9: MA03-1
T4, T5, T6, T7: BC337-25-NPN-TO92-CBE; TO92-CBE

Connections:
CTRL_4: R11.2; also elsewhere on the board
CTRL_5: R13.2; also elsewhere on the board
CTRL_6: R15.2; also elsewhere on the board
CTRL_7: R17.2; also elsewhere on the board
GND1: T4.E, T5.E, T6.E, T7.E; also elsewhere on the board
unnamed: CHARGING.A, R10.1
unnamed: CHARGING.C, D8.A, RLY4.2, T4.C
unnamed: R10.2, SV6.1
unnamed: R11.1, T4.B
unnamed: 10MEG.A, R12.1
unnamed: 10MEG.C, D9.A, RLY5.2, T5.C
unnamed: R12.2, SV7.1
unnamed: R13.1, T5.B
unnamed: 20MEG.A, R14.1
unnamed: 20MEG.C, D10.A, RLY6.2, T6.C
unnamed: R14.2, SV8.1
unnamed: R15.1, T6.B
unnamed: EXT-RL.A, R16.1
unnamed: D11.A, EXT-RL.C, RLY7.2, T7.C
unnamed: R16.2, SV9.1
unnamed: R17.1, T7.B
PWR_RELAY: D8.C, D9.C, D10.C, D11.C, RLY4.1, RLY5.1, RLY6.1, RLY7.1, SV6.2, SV7.2, SV8.2, SV9.2; also elsewhere on the board

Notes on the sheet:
LOAD CAPACITANCE [ON / OFF]
LOAD RESISTANCE RL-1 [ON / OFF]
LOAD RESISTANCE RL-2 [ON / OFF]
LOAD RESISTANCE RL-EXTERNAL [ON / OFF]

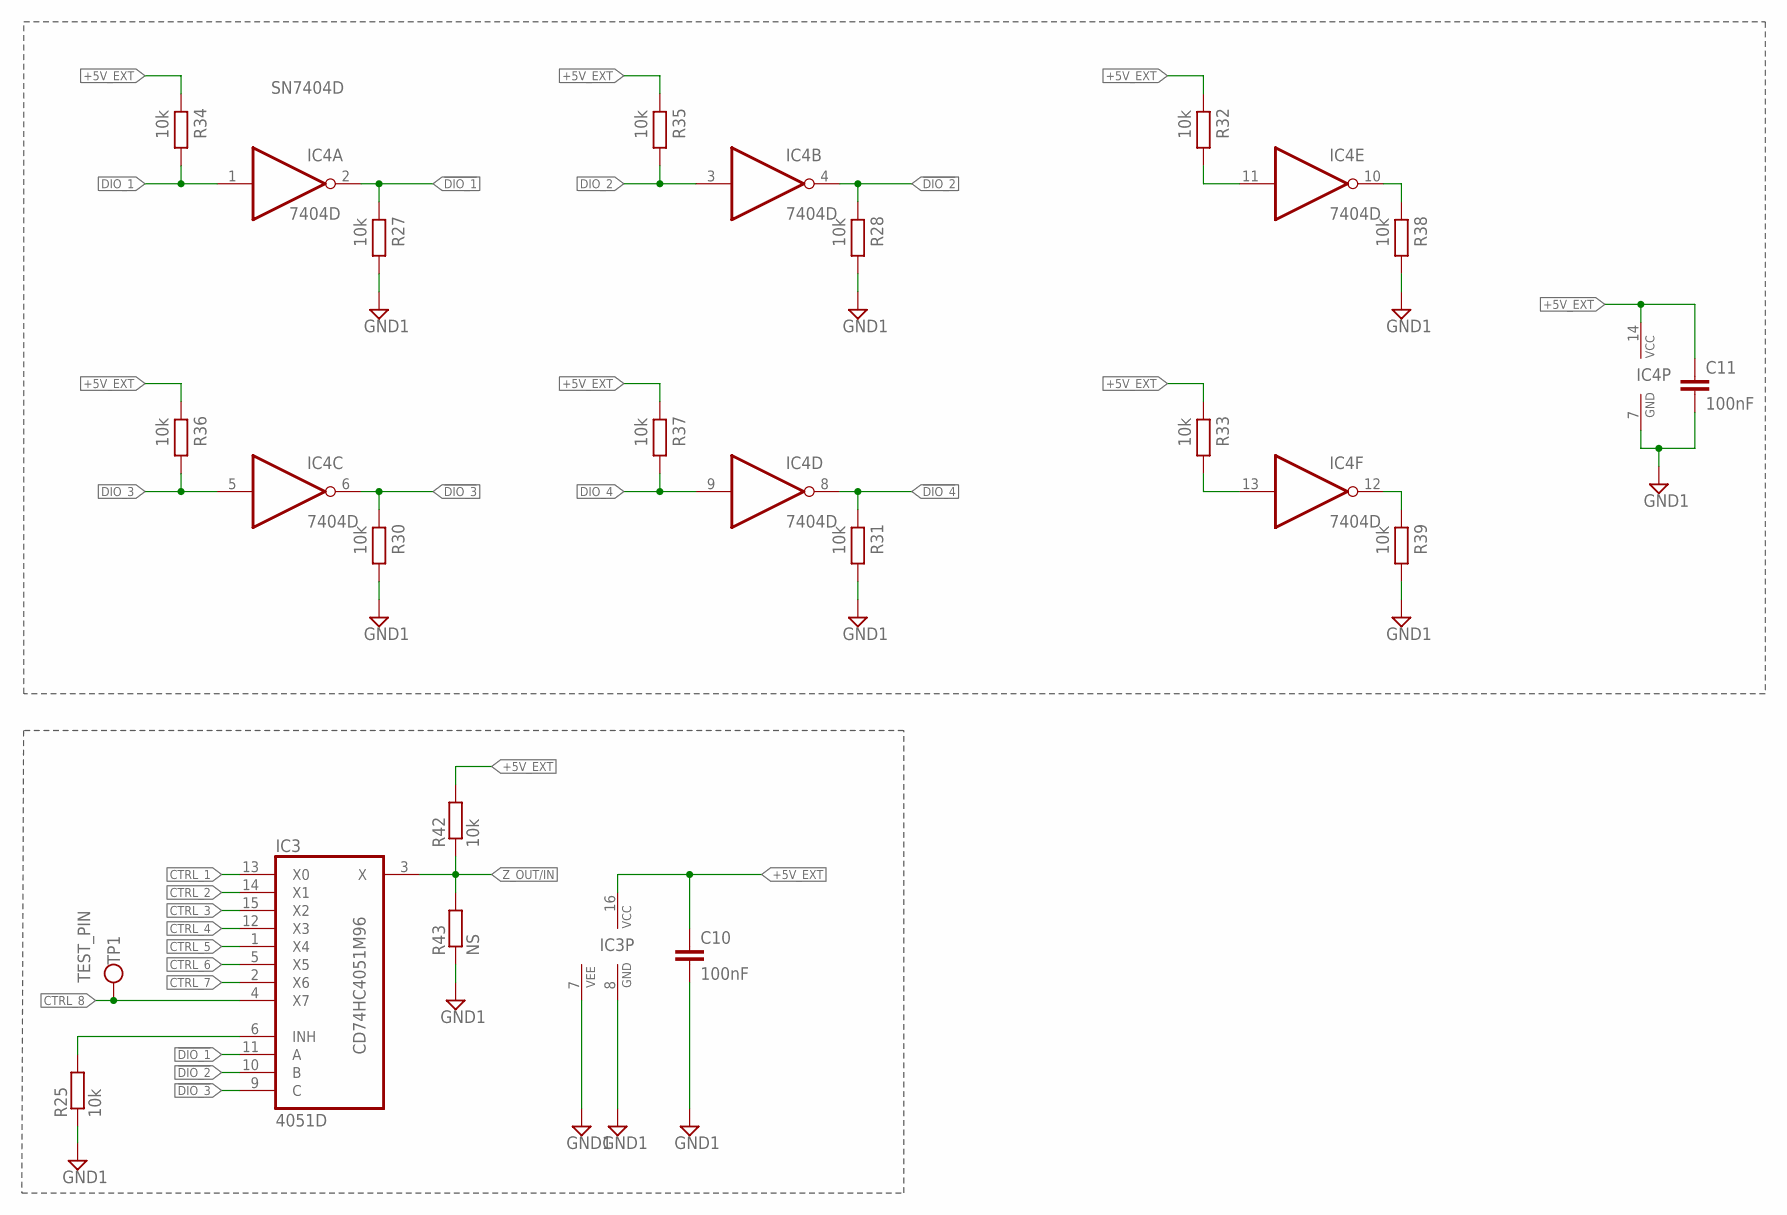
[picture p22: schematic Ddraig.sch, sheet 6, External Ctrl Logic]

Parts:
C10, C11: 100nF; C0805
IC3: 4051D; SO16
IC4: 7404D; SO14
R25, R27, R28, R30, R31, R32, R33, R34, R35, R36, R37, R38, R39, R42: 10k; R0805
R43: NS; R0805
TP1: TEST_PIN; 1-TEST_PIN

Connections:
!DIO_1: IC3.11 (A), IC4.2 (O), R27.2
!DIO_2: IC3.10 (B), IC4.4 (O), R28.2
!DIO_3: IC3.9 (C), IC4.6 (O), R30.2
!DIO_4: IC4.8 (O), R31.2
+5V_EXT: C10.1, C11.1, IC3.16 (VCC), IC4.14 (VCC), R32.2, R33.2, R34.2, R35.2, R36.2, R37.2, R42.2; also elsewhere on the board
CTRL_1: IC3.13 (X0); also elsewhere on the board
CTRL_2: IC3.14 (X1); also elsewhere on the board
CTRL_3: IC3.15 (X2); also elsewhere on the board
CTRL_4: IC3.12 (X3); also elsewhere on the board
CTRL_5: IC3.1 (X4); also elsewhere on the board
CTRL_6: IC3.5 (X5); also elsewhere on the board
CTRL_7: IC3.2 (X6); also elsewhere on the board
CTRL_8: IC3.4 (X7), TP1.1
DIO_1: IC4.1 (I), R34.1; also elsewhere on the board
DIO_2: IC4.3 (I), R35.1; also elsewhere on the board
DIO_3: IC4.5 (I), R36.1; also elsewhere on the board
DIO_4: IC4.9 (I), R37.1; also elsewhere on the board
GND1: C10.2, C11.2, IC3.7 (VEE), IC3.8 (GND), IC4.7 (GND), R25.1, R27.1, R28.1, R30.1, R31.1, R38.1, R39.1, R43.1; also elsewhere on the board
unnamed: IC4.11 (I), R32.1
unnamed: IC3.6 (INH), R25.2
unnamed: IC4.13 (I), R33.1
unnamed: IC4.10 (O), R38.2
unnamed: IC4.12 (O), R39.2
Z_OUT/IN: IC3.3 (X), R42.1, R43.2

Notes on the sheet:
CD74HC4051M96
SN7404D

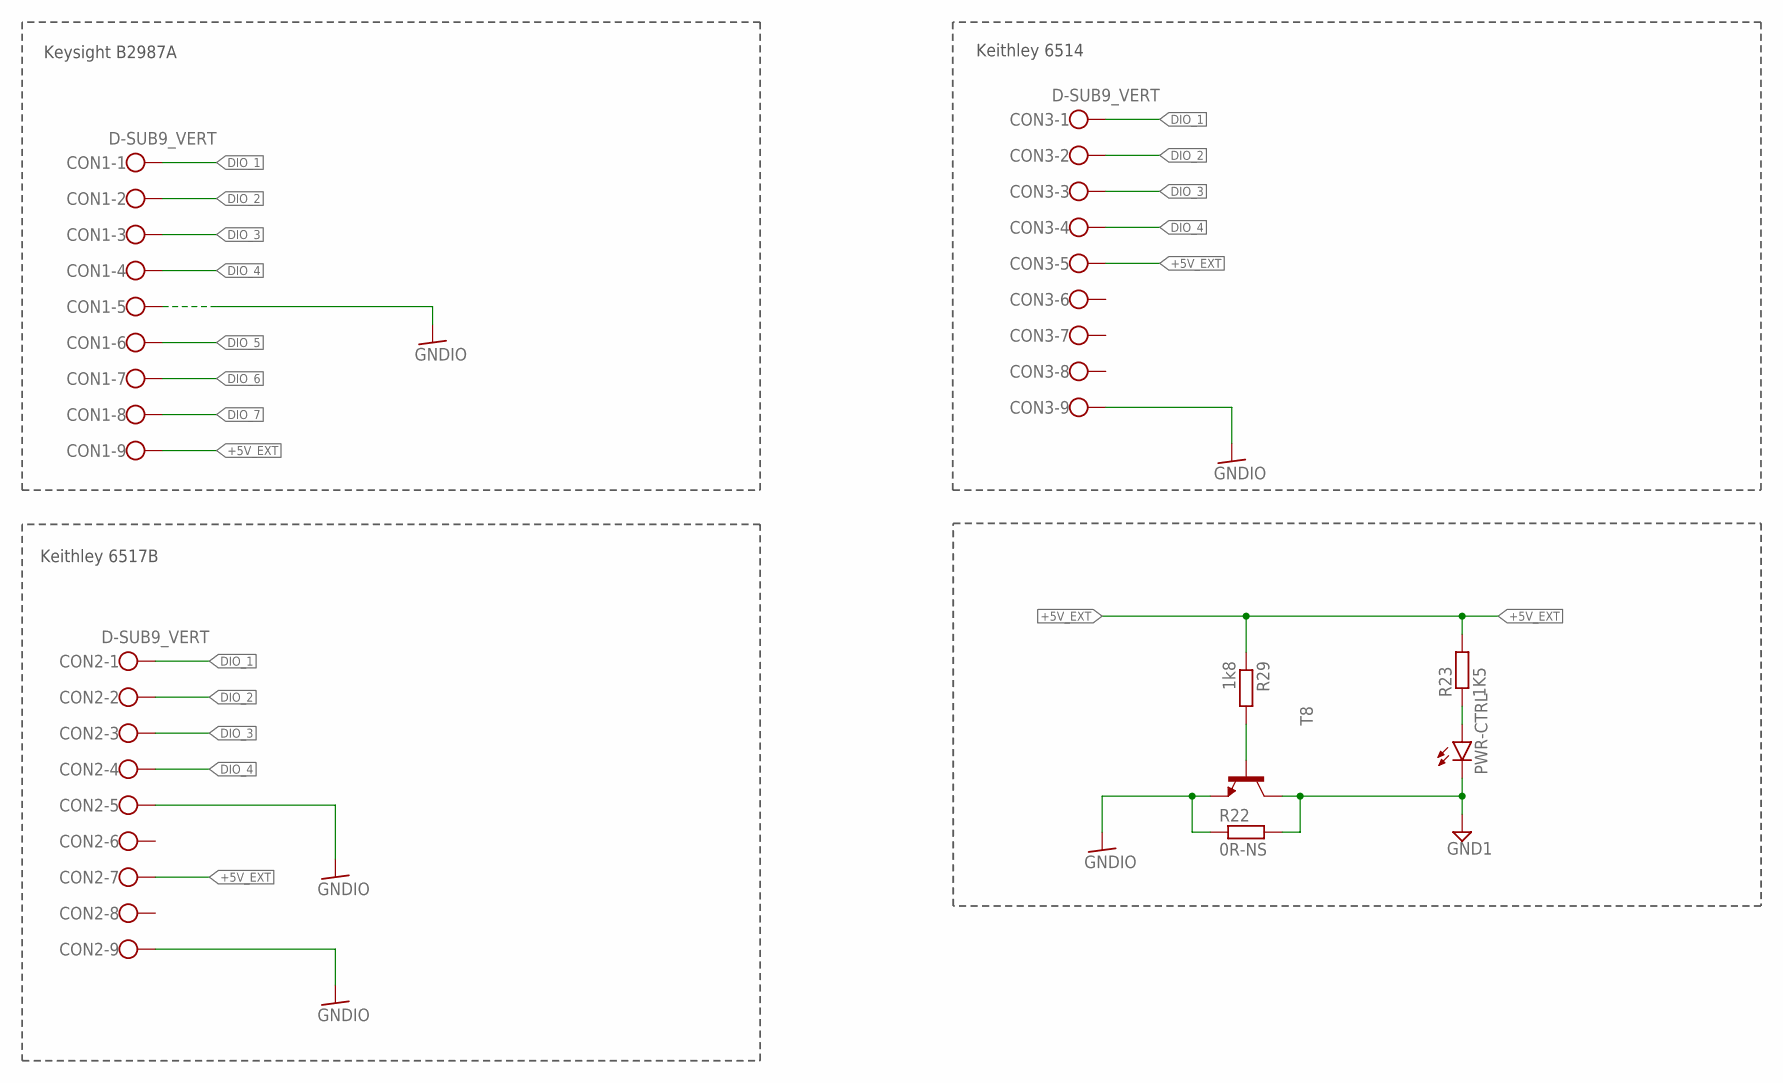
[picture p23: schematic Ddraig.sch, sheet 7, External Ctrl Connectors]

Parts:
CON1, CON2, CON3: D-SUB9_VERT; D-SUB9-VERTICAL
PWR-CTRL: LEDSMT1206; 1206
R22: 0R-NS; R0805
R23: 1K5; R0805
R29: 1k8; R0805
T8: BC337-25-NPN-TO92-CBE; TO92-CBE

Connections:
+5V_EXT: CON1.9, CON2.7, CON3.5, R23.2, R29.1; also elsewhere on the board
DIO_1: CON1.1, CON2.1, CON3.1; also elsewhere on the board
DIO_2: CON1.2, CON2.2, CON3.2; also elsewhere on the board
DIO_3: CON1.3, CON2.3, CON3.3; also elsewhere on the board
DIO_4: CON1.4, CON2.4, CON3.4; also elsewhere on the board
DIO_5: CON1.6
DIO_6: CON1.7
DIO_7: CON1.8
GND1: PWR-CTRL.C, R22.2, T8.C; also elsewhere on the board
GNDIO: CON1.5, CON2.5, CON2.9, CON3.9, R22.1, T8.E
unnamed: PWR-CTRL.A, R23.1
unnamed: R29.2, T8.B

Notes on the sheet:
Keysight B2987A
Keithley 6517B
Keithley 6514

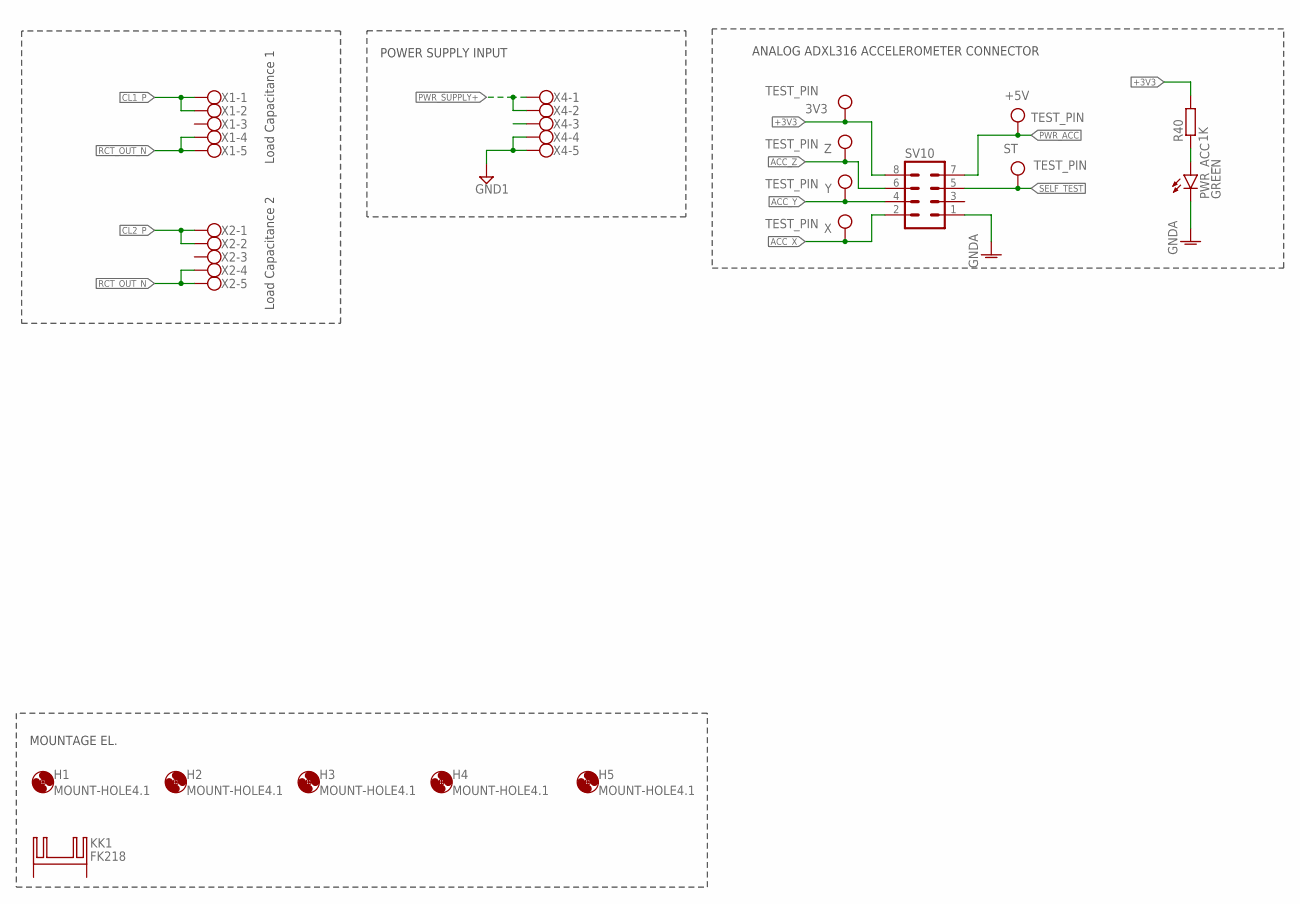
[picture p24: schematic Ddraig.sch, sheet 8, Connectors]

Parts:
3V3: TEST_PIN; 1-TEST_PIN
+5V: TEST_PIN; 1-TEST_PIN
H1, H2, H3, H4, H5: MOUNT-HOLE4.1; 4,1
KK1: FK218
PWR_ACC: GREEN; 1206
R40: 1K; R0805
ST: TEST_PIN; 1-TEST_PIN
SV10: MA04-2
X: TEST_PIN; 1-TEST_PIN
X1, X2, X4: 5PIN_CONN_RAST3.5MM
Y: TEST_PIN; 1-TEST_PIN
Z: TEST_PIN; 1-TEST_PIN

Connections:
+3V3: 3V3.1, R40.2, SV10.8
ACC_X: SV10.2, X.1
ACC_Y: SV10.4, Y.1
ACC_Z: SV10.6, Z.1
CL1_P: X1.1, X1.2; also elsewhere on the board
CL2_P: X2.1, X2.2; also elsewhere on the board
GND1: X4.4, X4.5; also elsewhere on the board
GNDA: PWR_ACC.C, SV10.1; also elsewhere on the board
unnamed: PWR_ACC.A, R40.1
PWR_ACC: +5V.1, SV10.7; also elsewhere on the board
PWR_SUPPLY+: X4.1, X4.2; also elsewhere on the board
RCT_OUT_N: X1.4, X1.5, X2.4, X2.5; also elsewhere on the board
SELF_TEST: ST.1, SV10.5

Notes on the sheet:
Load Capacitance 1
Load Capacitance 2
MOUNTAGE EL.
ANALOG ADXL316 ACCELEROMETER CONNECTOR
POWER SUPPLY INPUT

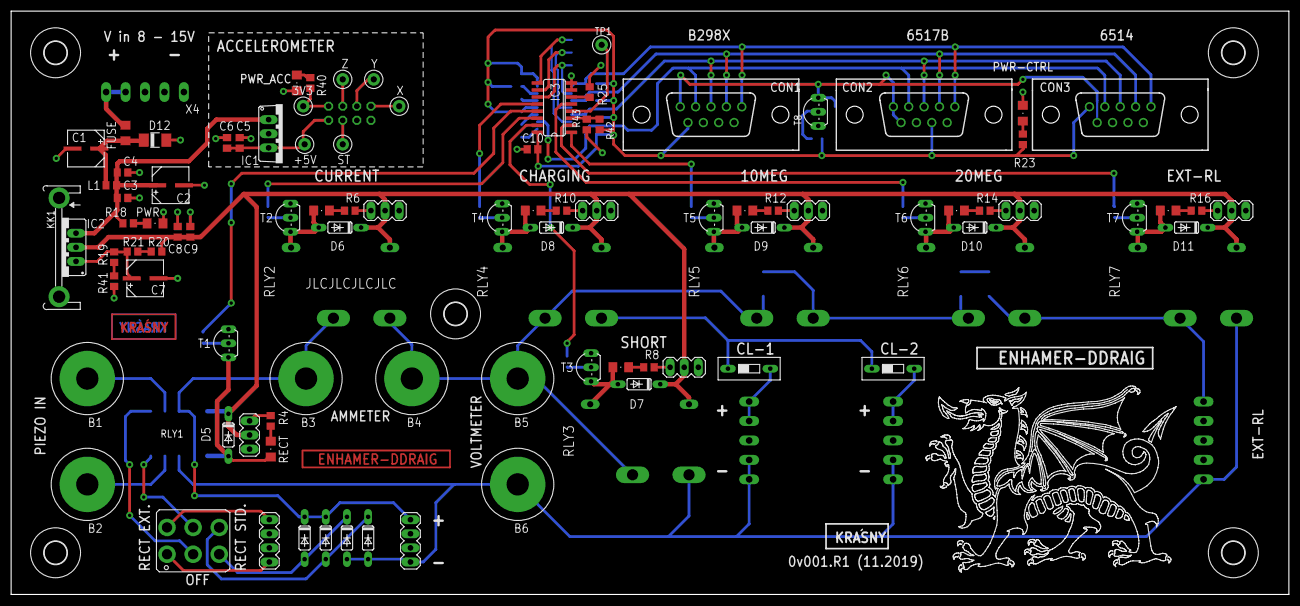
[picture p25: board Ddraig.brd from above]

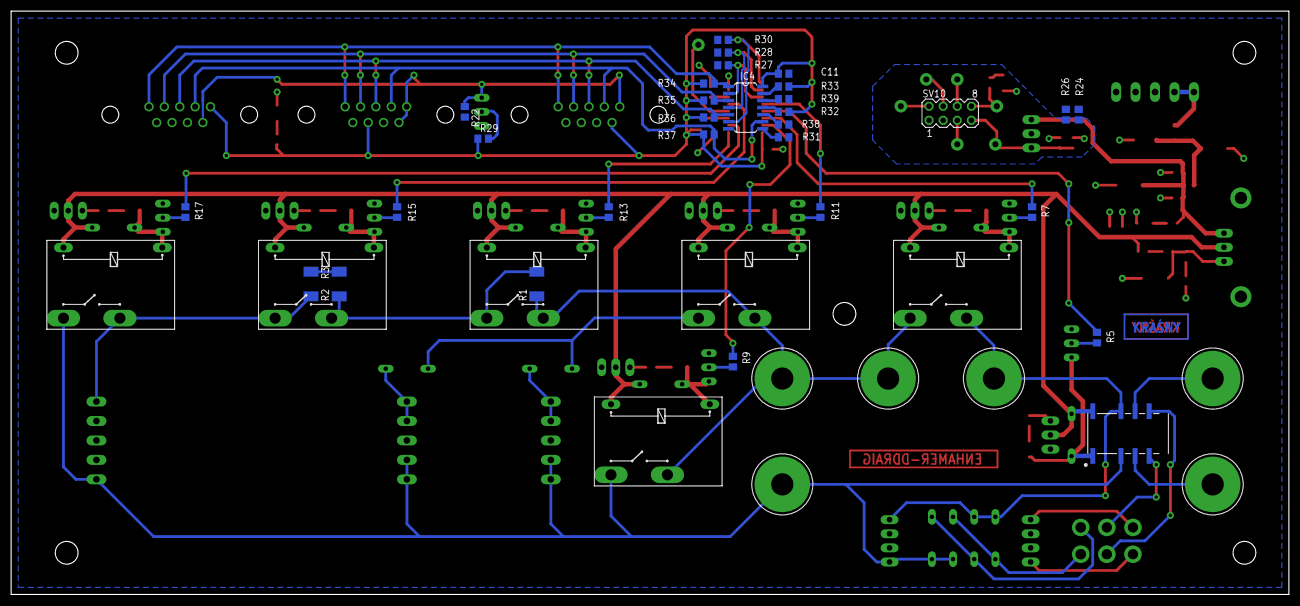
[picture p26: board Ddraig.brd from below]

Board: 2 copper layers, 230.0 x 105.0 mm, 136 parts (30 on the bottom side), 88 nets.
